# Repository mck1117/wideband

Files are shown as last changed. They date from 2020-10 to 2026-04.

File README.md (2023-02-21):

 

# rusEFI Wideband Controller

[User Documentation](https://rusefi.com/s/wb)

[Forum Thread](https://rusefi.com/forum/viewtopic.php?f=4&t=1856)

## Building Firmware

The `firmware/boards` directory contains configuration for each board this firmware supports.

For the standalone board and the module built in to rusEFI Hellen boards, `f0_module` is the correct target.  Use the `build_wideband.sh` script to build and package the wideband firmware: both a bin including the bootloader, and a header file consumed by rusEFI that contains no bootloader, to be uploaded over CAN (via the aforementioned bootloader).

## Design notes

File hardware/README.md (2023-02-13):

## `board_module`

Wideband O2 sensor controller on a postage stamp. Contains all the analog and digital control logic to handle a Bosch LSU 4.2, 4.9, or ADV sensor.

Intended to either be mounted on an ECU as a module, or on `board_carrier` to run standalone.

## `board_carrier`

Stacks under `board_module`, has 5v regulator, CAN tranceiver, etc so that the module can exist standlone.

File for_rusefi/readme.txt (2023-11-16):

The file wideband_image.h is generated for use by rusEFI to be able to beam firmware updates to attached wideband controllers.

Use ``cd firmware/boards/f0_module ; ./build_wideband.sh`` to build a fresh version.

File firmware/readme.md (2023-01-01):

# Implementation Details

Main logic is executed at a few KHz frequency (Bosch spec is 1-4KHz), driven by carefully selected ADC settings.

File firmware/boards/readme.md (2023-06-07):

Both single-channel and dual-channel F103 boards live at https://github.com/rusefi/rusefi-hardware

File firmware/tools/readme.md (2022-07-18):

* wideband.bin
 initial firmware with botb OpenBLT and current wideband firmware.

* wideband_update.srec
 rusEFI wideband firmware for OpenBLT-via-CAN or OpenBLT-via-uart update methods.

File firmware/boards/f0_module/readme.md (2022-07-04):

Firmware for reference https://github.com/mck1117/wideband/tree/master/board_module F0 hardware.

Also the firmware for https://github.com/andreika-git/hellen-one/tree/master/modules/wbo.

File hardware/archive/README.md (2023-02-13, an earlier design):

This folder is old hardware preserved for posterity.

## `board_dev`

Developmend board used to prove out principle before the F0 module was developed.

## `board_fw_tool`

Used to connect USB to the F0 module before the debug header was replaced with Tag Connect TC2030.

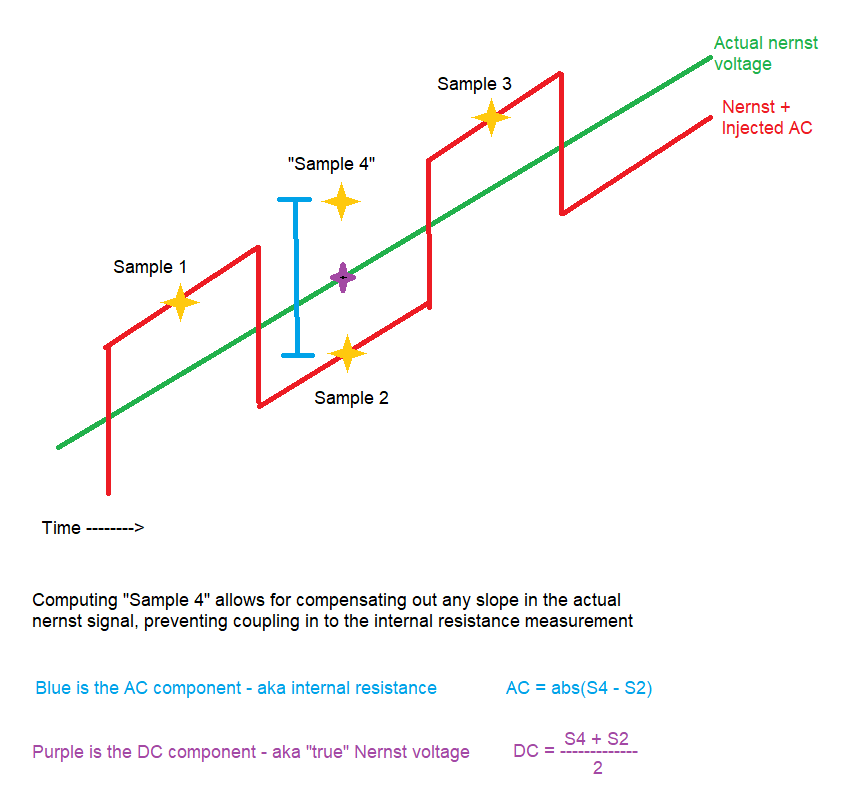
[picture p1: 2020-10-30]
firmware/sampling.png

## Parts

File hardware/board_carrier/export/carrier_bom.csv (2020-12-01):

Comment | Designator | Footprint | LCSC
1u | C1,C2,C3 | Capacitor_SMD:C_0603_1608Metric | C15849
47p | C4,C5 | Capacitor_SMD:C_0402_1005Metric | C1567
D_TVS | D1 | Diode_SMD:D_SMC | C133648
D_Schottky | D2 | Diode_SMD:D_SMA | C8678
220 | R1 | Resistor_SMD:R_0603_1608Metric | C22962
470 | R2 | Resistor_SMD:R_0603_1608Metric | C23179
TJA1051T-3 | U1 | Package_SO:SOIC-8_3.9x4.9mm_P1.27mm | C38695
LM78M05_TO252 | U2 | Package_TO_SOT_SMD:TO-252-2 | C58069

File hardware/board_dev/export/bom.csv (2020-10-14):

Comment | Designator | Footprint | LCSC
1u | C1,C4,C7,C14,C16 | Capacitor_SMD:C_0402_1005Metric | C52923
4.7u | C10 | Capacitor_SMD:C_0603_1608Metric | C19666
100n | C2 | Capacitor_SMD:C_0603_1608Metric | C14663
33n | C3 | Capacitor_SMD:C_0402_1005Metric | C1585
1n | C6 | Capacitor_SMD:C_0402_1005Metric | C1523
100n | C8,C5,C9,C11,C13,C12 | Capacitor_SMD:C_0402_1005Metric | C1525
RED | D1 | LED_SMD:LED_0603_1608Metric | C2286
GREEN | D2 | LED_SMD:LED_0603_1608Metric | C72043
BTS3028 | Q1 | Package_TO_SOT_SMD:TO-252-2 | C112639
61.9 | R10 | Resistor_SMD:R_0603_1608Metric | C23092
51k | R13 | Resistor_SMD:R_0402_1005Metric | C25794
3.3k | R14,R16,R24 | Resistor_SMD:R_0402_1005Metric | C25890
100k | R15,R17 | Resistor_SMD:R_0402_1005Metric | C25741
10k | R2,R11,R12,R4,R3,R18,R21,R20,R19,R29,R1,R33,R34 | Resistor_SMD:R_0402_1005Metric | C25744
10k | R22 | Resistor_SMD:R_0603_1608Metric | C25804
33 | R23 | Resistor_SMD:R_0402_1005Metric | C25105
1k | R25,R26,R27,R30 | Resistor_SMD:R_0402_1005Metric | C11702
68k | R32,R31 | Resistor_SMD:R_0402_1005Metric | C36871
22k | R6 | Resistor_SMD:R_0402_1005Metric | C25768
27k | R7,R5 | Resistor_SMD:R_0402_1005Metric | C25771
47 | R8 | Resistor_SMD:R_0402_1005Metric | C25118
10 | R9 | Resistor_SMD:R_0402_1005Metric | C25077
MCP6004 | U1,U2 | Package_SO:TSSOP-14_4.4x5mm_P0.65mm | C50282
STM32F042K6Ux | U4 | Package_DFN_QFN:QFN-32-1EP_5x5mm_P0.5mm_EP3.45x3.45mm | C110616
XC6206P332MR | U9 | Package_TO_SOT_SMD:SOT-23 | C5446

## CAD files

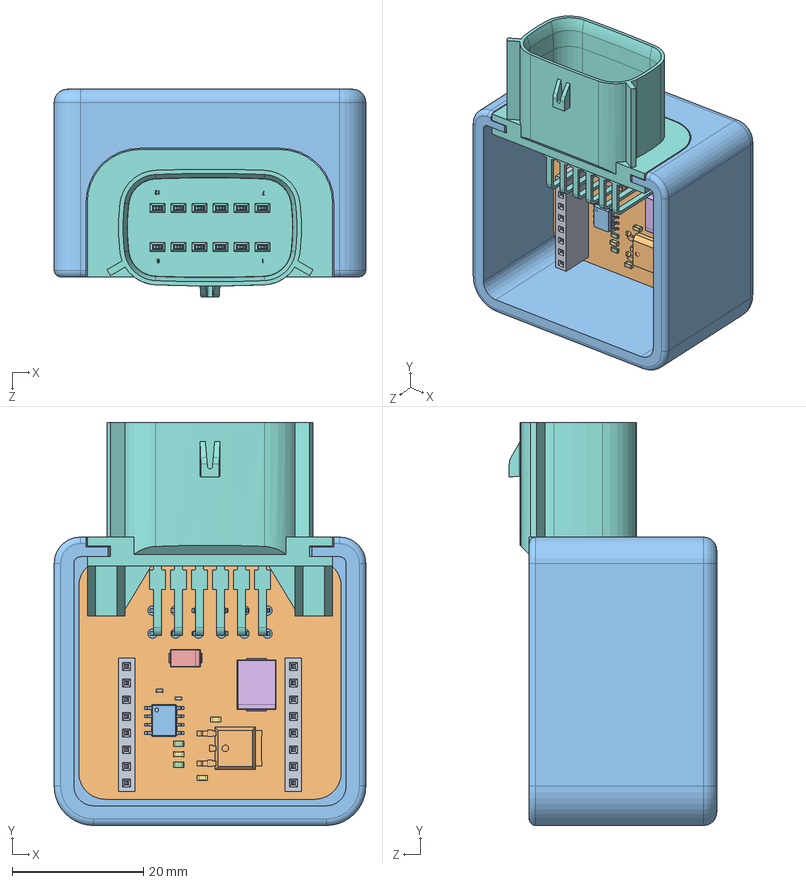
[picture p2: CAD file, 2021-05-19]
case/board_carrier.step.SLDASM
47.5 x 61.4 x 31.6 mm
SOLID.step x 2
SOLID-0.step
SOLID-1.step
SOLID-2.step x 2
SOLID-3.step
SOLID-4.step
SOLID-5.step x 3
COMPOUND.step
SOLID-6.step x 2
COMPOUND-7.step
Part13^board_carrier.step

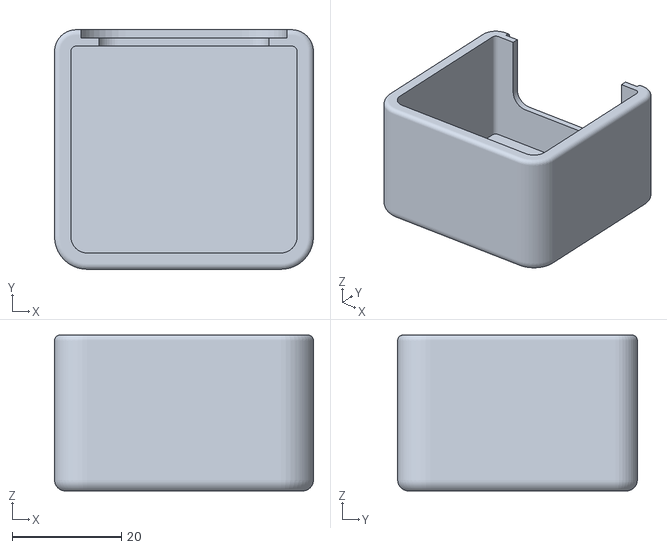
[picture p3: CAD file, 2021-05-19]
case/case.STL
47.5 x 44.0 x 28.6

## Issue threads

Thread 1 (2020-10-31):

programming usability and cheaper option

rusefillc, 2020-10-31:
At the moment that's a $8 with quantity 10 mostly assembled PCB which requires a $3.5 FTSH-107-01-F-DV-K

Please add TC2030 footprint like on microRusEFI since it's "free" and/or maybe some other programming option - 0.1" header? "program" button or jumper?

mck1117, 2020-10-31:
current board is a proof of concept/development board - no reason to not use a $4 connector there.  The "real thing" won't need it, instead firmware upload over UART DFU or something.  I don't really need debugging facilities on the production one, and if I decide I do, a few test pads for SWD are good enough.

Closed 2020-10-31.

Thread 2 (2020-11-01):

opamp alternatives

mck1117, 2020-11-01:
Possible alternatives to the MCP6004:

|PN|Vos typ|Rail-to-rail?|JLC cost @qty 10|
|--|--|--|--|
|MCP6004|4.5mV|25mV|$0.29|
|AD8609|40uV|~20mv|$2.20|
|OPA4377|250uV|10-20mV|$1.38|
|RS8559XQ|20uV|10mV|$0.54|
|MCP6L04|1mV|35mV|$0.25|

mck1117, 2020-12-11:
switched to ad8628 on the module

Closed 2020-12-11.

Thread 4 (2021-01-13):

Embeddable module

rusefillc, 2021-01-13:
I am interested in a single self-contained PCB block for embedding into other boards

A rectangle KiCad without holes for connectors but with all connectivity routed to edges and a footprint symbol

rusefillc, 2021-06-13:
we now have https://github.com/andreika-git/hellen-one/wiki/module-wbo

Closed 2021-06-13.

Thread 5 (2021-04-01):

chip shortage in 32 pin package

rusefillc, 2021-04-01:
as is we use STM32F042K6Tx

STM32F042K6T6 or STM32F042K6T7

https://jlcpcb.com/parts/componentSearch?searchTxt=stm32%20p-32

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

would STM32F103C8T6 or STM32F030C8T6 or else in 48 pad package be an option?

rusefillc, 2021-04-13:
chip shortage is harder on chips with CAN. can we add analog output into WBO module please? i like analog more than uart while we are in survival mode and we will go back to CAN once we can?

Closed 2022-08-17.

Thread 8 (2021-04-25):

clamp esr over CAN to prevent overflow

mck1117, 2021-04-25:

mck1117, 2021-04-28:
Done in master.

Closed 2021-04-28.

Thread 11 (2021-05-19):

hardware support for hard-coded index

mck1117, 2021-05-19:
Somehow we need to hard-code index on PnP hellen boards with multiple controllers.  It's impossible to unplug one controller to set index, since they're all hard wired on the same pcb.

mck1117, 2021-05-19:
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

mck1117, 2021-05-19:
For legacy boards without jumpers, pins were selected such that ID 0 and 1 are possible by bridging to adjacent power pins:
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

mck1117, 2021-05-19:
now supported via 48dbdb842eae69c1f04c9a79e712a42da6d8ad18

Closed 2021-05-28.

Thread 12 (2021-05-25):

Analog output

rusefillc, 2021-05-25:
Humans are looking for wideband 0-5v analog output. Maybe a simple 0-3v output would do?

mck1117, 2021-05-26:
Which humans? Why? We want to promote rusEFI, so why not encourage CAN?

rusefillc, 2021-05-26:
Questionable cheap humans for sure, but being known for a good & cheap WBO could be the long shot way to get people familiar and comfortable with RE.

shinobisystems, 2021-09-28:
Support the addition of an analogue output line (pref 0-5v) on the connector for correlation to gauges for non-EFI / Other ECU applications.. Lets make it available to Everyone out there to prove the Products Superiority (as well as Flexibility)...

Closed 2022-08-17.

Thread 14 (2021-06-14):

We need a 52mm screen option

rusefillc, 2021-06-14:
Without an easy to install gauge we are just taking too much risk in my opinion

Closed 2022-08-17.

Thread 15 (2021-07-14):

Make CAN protocol option to emulate MoTeC LTC/D.

kjngineering, 2021-07-14:
The MoTeC LTC (Lambda to CAN) devices are essentially the exact same functionality of this device.
The price of these devices is ~$380USD for the single channel version and $500USD for the dual.

Consider the commercial option of matching the can protocol to the MoTeC device as described here (Appendix E):
https://www.motec.com.au/filedownload.php/LTC%20User%20Manual.pdf?docid=3001

This would not be the first device to go down this route with the Bosch Motorsport Lambdatronic LT2 sport being available with a "MoTeC Compatible" CAN bus protocol:
https://cdn.shopify.com/s/files/1/0057/7712/9587/files/LT2_Sport_Lambda_Measurement_Device_-_Datasheet.pdf

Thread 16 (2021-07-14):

Add hardware for onboard voltage sensing.

kjngineering, 2021-07-14:
Currently the controller uses the voltage sensed at the ECU and transmitted via CAN to adjust the heater PID.
Chassis wiring and ground points could mean reasonable differences between the battery voltage at the module and the ECU.

Suggest incorporating an ADC channel and appropriate divider on the module to measure "local" battery voltage for heater compensation.

rusefillc, 2023-02-03:
Another argument for same would be having 042 design self-contained.

rusefillc, 2023-02-03:
https://rusefi.com/forum/viewtopic.php?p=47055#p47055

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

rusefillc, 2023-02-03:
Another option https://github.com/mck1117/wideband/issues/194

mck1117, 2023-02-03:
hardware done 6831f5a1ae87e985e1e40e1fd2b6fe2107d40a72

Closed 2023-02-04.

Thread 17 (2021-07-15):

Add switchable RC circuits to support LSU-4.9 and LSU-ADV?

kjngineering, 2021-07-15:
Much like the ST driver it makes sense to have switchable RC circuits to support different sensors.
Eventually the LSU-ADV will become the standard part.

rusefillc, 2022-04-04:
https://www.bosch-motorsport.com/content/downloads/Raceparts/Resources/pdf/Data%20sheet_69086859_Lambda_Sensor_LSU_ADV/ADV_pre_Turbo.pdf

@kjngineering any part numbers for me to purchase a test LSU-ADV for @dron0gus?

kjngineering, 2022-04-04:
Updated datasheet with Bosch Global PN: https://www.efisolutions.com.au/assets/brochures/135-017.pdf

Post-Turbo: 0 258 027 010
Pre-Turbo: 0 258 027 211

Some Links:
https://www.14point7.com/products/lsu-adv-wideband-o2-sensor
https://www.efisolutions.com.au/bosch-sensor-lsu-adv-wideband-sensor

rusefillc, 2022-04-04:
@kjngineering while those are amazing links i would expect something more OEMish to be cheaper?

either OEM has used ADV somewhere (and we should learn where) or if ADV is just for the fanciest guys there maybe we are not there yet

kjngineering, 2022-04-04:
I did see some OEM cross reference for these but they were out of stock and around the 80EUR level. What is the preferred country of purchase?

rusefillc, 2022-04-04:
USA new/used ebay.com
RU used by model/year

my focus is mostly to make sure that we have a "proper" source

kjngineering, 2022-04-04:
So its apparently the same as Audi/VW/Porsche: 06L906262 (unconfimed)

https://www.ebay.com/itm/334323999253

rusefillc, 2022-04-04:
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

kjngineering, 2022-04-04:
> 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

This is bosch OE 0 258 027 174, according to the product subcategory on buycarparts.co.uk this is a LSUADV sensor.
However, according to the information available on the Audi catalog this is a pre-turbo variant.

The 'best' way to identify a LSU-ADV at the moment is the connector type, they have 5 pins and no internal trim resistor. (this sensor is in line with this information).

mck1117, 2022-04-04:
> this is a pre-turbo variant.

I think the pre-turbo operates the same as the "normal" LSU ADV, but has different thermal behavior

rusefillc, 2022-04-07:
Some info at https://rusefi.com/forum/viewtopic.php?p=44904#p44904

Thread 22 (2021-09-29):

mosfet PN alternatives

rusefillc, 2021-09-29:
See https://github.com/andreika-git/hellen-one/issues/96

Closed 2022-08-17.

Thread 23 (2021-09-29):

through-hole option for MOSFET

rusefillc, 2021-09-29:
See https://github.com/andreika-git/hellen-one/issues/97 as ultimate chip shortage solution

mck1117, 2021-09-29:
Nope, not worth the vibration risk here.  There are plenty of protected DPAK low side drivers.

Closed 2021-09-29.

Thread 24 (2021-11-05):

Access to I2C bootloader

rusefillc, 2021-11-05:
it would be great to reduce manual labor while boards assembly, is there a way to big rusEFI to program WB controllers from scratch?

stm32f042 does not have CAN bootloader. What about I2C? what level of effort on HW and SW side to get all that to work?

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

Closed 2022-08-17.

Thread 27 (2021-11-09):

Carrier, Parts shortage, BOM D1

rusefillc, 2021-11-09:
D1 | D_TVS | SMCJ30CA-TR not available right now any alternatives?

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

rusefillc, 2021-11-10:
@blundar says
SMCJ28CA C10245
C111086 SMCJ30CA

Closed 2022-08-17.

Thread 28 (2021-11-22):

F103 port of firmware

rusefillc, 2021-11-22:
We have https://github.com/mck1117/wideband/tree/master/firmware compiled with https://github.com/mck1117/wideband/tree/master/firmware/boards/f0_module running on https://github.com/mck1117/wideband/tree/master/board_module - that's working F042 reference

We also have untested F103 version of the hardware https://github.com/rusefi/rusefi-hardware/tree/main/wideband-F103 which still needs firmware

Looks like https://github.com/mck1117/wideband/tree/master/firmware/boards/f1_dave is the skeleton which needs F103-specific details

rusefillc, 2022-01-11:
open issues:
1) CANConfig
1) software PWM callback for output toggle

Closed 2022-08-17.

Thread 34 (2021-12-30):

Wideband failed to startup after cranking

BeerMoneyMotorsports, 2021-12-30:
Log Below- wbo never showed a reading after engine started.  after a few minutes, i did a firmware write on the wbo while engine running.  45 seconds later, wbo was reading like it should.

https://rusefi.com/online/view.php?log=524

BeerMoneyMotorsports  6:00 PM
@Matthew Kennedy so i have noticed an issue with wbo when long cranking.  i will try to get a log of it and create an issue.
It seem that if you take too long to start or it fails to start, the sensor will not read.  I noticed this while testing on this NB1.

Matthew Kennedy  6:00 PM
hm

BeerMoneyMotorsports  6:00 PM
i have let it run after the car started for a couple minutes
6:00
sensor never shows up

Matthew Kennedy  6:00 PM
loggy log in wbo debug mode

BeerMoneyMotorsports  6:01 PM
i can flash the wbo firmware real quick and then it will heatup and work
6:01
while engine is still running

Matthew Kennedy  6:01 PM
yea
6:01
whatever thermal conditions you're making are probably just barely outside what it can handle

BeerMoneyMotorsports  6:01 PM
ill do a good log tomorrow and toss it in an issue with a reasonable description

Matthew Kennedy  6:01 PM
which means we just need to widen the envelope of "legal" and/or adjust heater tuning a bit (edited)

BeerMoneyMotorsports  6:02 PM
it seems like its related to the rpm requirement for heating.  does it trip out if jumping between low and high rpm?  or when trig errors occur?

BeerMoneyMotorsports  12:13 PM
@Matthew Kennedy https://rusefi.com/online/view.php?log=524

rusefi.comrusefi.com
rusEFI online
rusEFI tune file sharing site
12:14
wbo never started to read after startup.  after a few minutes, i did a firmware write on the wbo while engine running.  45 seconds later, wbo was reading like it should

BeerMoneyMotorsports  1:36 PM
Which repo do i ticket?

Matthew Kennedy  1:41 PM
Do it in mine
1:41
Probably a bug in the wbo itself

mck1117, 2022-01-10:
likely fixed by 437efb1cc6f5db2aebb5fa5fa3f2d8bebf3716c6

BeerMoneyMotorsports, 2022-01-14:
firmware update but wbo still inop

https://rusefi.com/online/view.php?log=566

BeerMoneyMotorsports, 2022-01-17:
latest firmware (1/17/2022) with no failure.

https://rusefi.com/online/view.php?log=575

Closed 2022-10-03.

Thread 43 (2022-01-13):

F103 no longer blinks

rusefillc, 2022-01-13:
F103 FW was blinking green LED before https://github.com/mck1117/wideband/commit/23a05968d3eaa2c6a9e326138c931f02467fbbad
F103 FW no longer blinks green LED after https://github.com/mck1117/wideband/commit/23a05968d3eaa2c6a9e326138c931f02467fbbad

mck1117, 2022-01-13:
try again with 660dad473ce2e0721438f7be5749fd3e449680c7

rusefillc, 2022-01-13:
it's blinking again!

mck1117, 2022-01-13:
OK, I guess something didn't like 64MHz.  Let's stay at 48 for now then, and maybe speed it up later.

Closed 2022-01-13.

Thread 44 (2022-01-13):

F103 CAN baud rate

rusefillc, 2022-01-13:
Steps to reproduce:
no real WBO hardware needed, blue pull and logic analyzer should be enough (?)

```
cd firmware
make -j12 BOARD=f1_dave
```

before https://github.com/mck1117/wideband/commit/86034506b07e8c83ea32b3456d0b44037c6cc9da we had

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

rusefillc, 2022-01-13:
after https://github.com/mck1117/wideband/commit/86034506b07e8c83ea32b3456d0b44037c6cc9da we have
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

rusefillc, 2022-01-13:
@blundar great news HW works with 250K version of FW

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

mck1117, 2022-01-13:
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

rusefillc, 2022-01-13:
I cannot explain it i just report my test results sorry

rusefillc, 2022-01-23:
Just to confirm - is it OK to test with a blue pill with logic analyzer?

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

thirstyone, 2022-01-24:
don't you need some other devices on the bus?

rusefillc, 2022-01-24:
@thirstyone please consider using more words. We are trying to discuss pretty complex issues here and in my opinion short form is not effective. If you are looking to help please consider typing a bit more works to spell things out a bit more explicitly.

@thirstyone stm32 uses TTL levels on RX and TX pins right? Are you saying that without a real transceiver and without loopback I would never see CAN peripheral TTLing anything readable?

mck1117, 2022-01-24:
> without loopback I would never see CAN peripheral TTLing anything readable?

tie TX and RX together, with a 1k pullup to 3.3v, you don't need a CAN tranciever, but you may need a "bus" enough to fake it.

rusefillc, 2022-01-24:
@thirstyone thank you - with real bus I got 8MHz F103 to work! (alligator clips are wired to CANHacker with 120R)

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

rusefillc, 2022-01-24:
and F103 WBO firmware CAN works as well as is on this blue pill setup, I have no idea what was wrong with my previous experiments on real WBO board

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

Closed 2022-01-24.

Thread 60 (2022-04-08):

Bluetooth

rusefillc, 2022-04-08:
We have UART, we have no screen... Sounds like bluetooth to me?

rusefillc, 2022-04-08:
For hardware see https://github.com/rusefi/rusefi-hardware/issues/58

Closed 2022-08-17.

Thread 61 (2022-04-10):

voltage reference BOM cost

rusefillc, 2022-04-10:
At the moment REF3033  ±0.2% 75ppm/°C 3.3V SOT-23(SOT-23-3) Voltage References is used which is a $1.6 part

Is there a cheaper solution? what level of precision is needed? could it be accomplished with an adjustable reference like AZ432ANTR-E1?

https://datasheet.lcsc.com/lcsc/1810251610_Diodes-Incorporated-AZ432ANTR-E1_C84139.pdf

Closed 2022-08-17.

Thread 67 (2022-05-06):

virtual zero range should be 5v not 3.4v

rusefillc, 2022-05-06:
for better AFR range we shall have wider virtual ground range

mck1117, 2022-05-11:
No need. The circuit was designed to use the full range of the sensor, which we do.

If someone can quantify an actual problem, I am happy to consider it.

rusefillc, 2022-05-11:
is it about higher current in order to get quicker response time?

mck1117, 2022-05-11:
> logging used current

We measure that directly with the pump measurement resistor and amp - then convert to lambda.

We do also directly output the raw pump dac value: https://github.com/mck1117/wideband/blob/2167016c169925023510ef98a7c5abf38c2408f5/firmware/can.cpp#L158

Closed 2022-05-11.

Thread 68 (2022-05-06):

DAC and PID nerst control is not the best control strategy

rusefillc, 2022-05-06:
usecase: in-range measurment adter out-of-range condition

DAC and PID are not best for return to into range phase of control

suggested soltion: analog control, differential op-amp in diff schematic

rusefillc, 2022-05-07:
@mck1117 says

our digital loop runs at ~2khz
if it ran at 10hz maybe

but we're much faster than the bandwidth of the sensor

shannon/nyquist say digital and analog are "the same" if you're sufficiently faster than the bandwidth of any signal you care about

mck1117, 2022-05-11:
I have yet to see a problem with it. I've seen full scale swings (in closed loop!) in <0.1 second.

Closed 2022-05-11.

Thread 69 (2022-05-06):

780C is very imporant

rusefillc, 2022-05-06:
nerst cell resistance control by variable voltage - sin wave etc

NIck RMS says that keeping (heater?) at precisely 780C is really important. Sin wave was a suggested implementation detail.

mck1117, 2022-05-11:
wat?

rusefillc, 2022-05-11:
@dron0gus do you want to get in touch with Nick RMS and do the translation? :)

dron0gus, 2022-05-12:
@rusefillc yes, I can try.

Closed 2022-08-17.

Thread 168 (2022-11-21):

AUX output

pink-fr3ud, 2022-11-21:
Hi,
Thank you for sharing this.
I was looking at your schematics to design a board with in stock components from JLCPCB assembled
I can't find where the analog output is, as stated in the forum https://rusefi.com/forum/viewtopic.php?f=4&t=1856
In fact, the STM32F042K6T6 doesn't provide a DAC at all...? I see in auxout.cpp you are doing some PWM things, is it how you produce the analog signal?
The STM32G030K6T6 go for as little as $1.1150, is pin to pin compatible, faster, has more memory, DAC ... newer. Maybe a good candidate?

rusefillc, 2022-11-21:
> HI can't find where the analog output is, as stated in the forum https://rusefi.com/forum/viewtopic.php?f=4&t=1856

There are 131 posts in that https://rusefi.com/forum/viewtopic.php?f=4&t=1856 thread please be more specific?

Original hardware design does not have AUX output on purpose, it's only the F103 alternative designs which are trying to add aux output. But those F103 efforts are in a bit of an unclear state poke @dron0gus

See also #12

pink-fr3ud, 2022-11-21:
Sorry I was refering to #1 post :
"Support both in-ECU use, as well as standalone. That means SPI or serial comms with an ECU, and CAN or analog for external use."
My bad I didn't see that the F103 was derivated from your design, and indeed he confirmed the DAC working too
I will read a bit more about it and see if I can propose something similar with another mcu

For sure 1.129 Lambda seems poor enough for most tuning needs
Thank you

mck1117, 2022-11-21:
Internal and external original design options are both CAN bus

Closed 2022-11-21.

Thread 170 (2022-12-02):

hard fault on boot with GCC 11

mck1117, 2022-12-02:
Looks like we hard fault the first time we touch a floating point number when compiled with GCC 11. We're using soft floats (ie, no hardware fpu), what is going on!?

rusefillc, 2022-12-02:
@dron0gus

mck1117, 2022-12-02:
it looks like this might be a gcc11 issue…….stay tuned

dron0gus, 2022-12-02:
I bet on stack overflow. My feeling is that GCC11 produce code that uses more stack.

mck1117, 2022-12-02:
Problem happens on F1, but not F0.

F0 = cortex-m0 aka ARMv6-M
F1 = cortex-m3 aka aARMv7-M

mck1117, 2022-12-02:
|Compiler|F0?|F1?|
|---|---|---|
|GCC 9.3.1|❎|❎|
|GCC 11.3.1|❎|❌|

dron0gus, 2022-12-02:
@mck1117 your master. f1_dual with GD32. GCC11.3.rel1. No HardFault.

```
(gdb) info thread
  Id   Target Id                                                  Frame
  2    Thread 536873560 (Name: main, State: SLEEPING)             chSchGoSleepS (newstate=8 '\b') at ChibiOS/os/rt/src/chschd.c:558
  3    Thread 536873776 (Name: idle, State: CURRENT)              chSchDoPreemption () at ChibiOS/os/rt/src/chschd.c:765
  4    Thread 536876976 (Name: noname, State: SUSPENDED)          chSchGoSleepS (newstate=3 '\003') at ChibiOS/os/rt/src/chschd.c:558
  5    Thread 536877552 (Name: noname, State: SLEEPING)           chSchGoSleepS (newstate=8 '\b') at ChibiOS/os/rt/src/chschd.c:558
  6    Thread 536878056 (Name: noname, State: SLEEPING)           chSchGoSleepS (newstate=8 '\b') at ChibiOS/os/rt/src/chschd.c:558
  7    Thread 536880360 (Name: noname, State: SLEEPING)           chSchGoSleepS (newstate=8 '\b') at ChibiOS/os/rt/src/chschd.c:558
  8    Thread 536875744 (Name: noname, State: QUEUED)             chSchGoSleepS (newstate=4 '\004') at ChibiOS/os/rt/src/chschd.c:558
  9    Thread 536876456 (Name: noname, State: QUEUED)             chSchGoSleepS (newstate=4 '\004') at ChibiOS/os/rt/src/chschd.c:558
  10   Thread 536879864 (Name: Primary TS Channel, State: QUEUED) chSchGoSleepS (newstate=4 '\004') at ChibiOS/os/rt/src/chschd.c:558
  11   Thread 536878824 (Name: egt, State: SLEEPING)              chSchGoSleepS (newstate=8 '\b') at ChibiOS/os/rt/src/chschd.c:558

```

mck1117, 2022-12-02:
can you attach your `wideband.elf`/`wideband.list`/`wideband.map` that are working?

dron0gus, 2022-12-02:
[wideband.zip](https://github.com/mck1117/wideband/files/10144405/wideband.zip)

mck1117, 2022-12-03:
no crash running your elf on my board

mck1117, 2022-12-03:
double interesting: running the build from github actions does NOT crash, works fine

mck1117, 2022-12-03:
I had a bad compiler install, it turns out if you end up with the wrong `bits/c++config.h`, strange things happen!

Closed 2022-12-03.

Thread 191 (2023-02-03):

kicad5 or kicad 6?

rusefillc, 2023-02-03:
Is this repo using kicad 5 or kicad 6 or is the intention to support both?

mck1117, 2023-02-03:
as of yesterday it's a split because the module is now 6

rusefillc, 2023-02-03:
should https://github.com/mck1117/wideband/blob/master/hardware/board_module/wideband_controller.pro be removed?

mck1117, 2023-02-03:
8dee668662ecc28bb1afb52380e18ca647ca92fd

Closed 2023-02-03.

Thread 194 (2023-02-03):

042 design as standalone not rusEFI WBO

rusefillc, 2023-02-03:
Could current 042 offering be used not on rusEFI as is?

What are all the gaps between current design and not-rusEFI usage?

* battery input only via CAN?  https://github.com/mck1117/wideband/issues/16
* limited SEL options? https://github.com/mck1117/wideband/issues/193

Anything else?

rusefillc, 2023-02-28:
Poke :) Looks like we have relevant HW progress but no SW progress? Was HW progress a fluke? Is it complete?

rusefillc, 2023-11-15:
How about fallback to some hard-coded voltage assumption if no CAN RX happens for x number of seconds?

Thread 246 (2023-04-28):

Bosch sensors

ChubbyBunny1, 2023-04-28:
Not sure if here is the correct place to ask a question.
I have bought an bosch LSU4.9 that is specific fitment for some vehicles. The part number is 0258017617. Is there any chance that this sensor is specific to some vehicle ECUs? Also what are the differences on theese all bosch LSU4.9 sensors apart from their cable length?

ChubbyBunny1, 2023-04-28:
Thanks for the info, i bought it from theese generic online parts store where you place your VIN and it gives you parts for your car with differnt pricing and company selections. It says bosch and the price was 60euros. Once arrived, i compared it to known original bosch LSU4.9 and the writings and the markings seemed legit.

mck1117, 2023-04-29:
I'll close for now then. If you end up having a problem with a particular (but legitimate Bosch) sensor, come back and we'll have a look.

Closed 2023-04-29.

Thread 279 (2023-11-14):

is anything broken on this log?

rusefillc, 2023-11-14:
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

[wbo-log.zip](https://github.com/mck1117/wideband/files/13345168/wbo-log.zip)

mck1117, 2023-11-15:
the state of the heater request should be in that log too

mck1117, 2023-11-16:
Looks like the ECU isn't requesting the heater to be on, so it isn't trying to heat. Everything looks fine from WBO side.

Closed 2023-11-16.

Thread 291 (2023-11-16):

switch to use libfirmware timer

mck1117, 2023-11-16:
Current issue:

Why is this here, instead of util.mk?
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

rusefillc, 2023-11-16:
I assume that timer.cpp assumes some "abstract" methods are implemented by the consumer.

In order for consumers to have an option not to use timer.cpp and thus not implement dependencies it's currently not in util.mk

I am open to all improvements! At the moment I believe the consumers of libfirmware are ECU, WBO, GDI4 and stim.

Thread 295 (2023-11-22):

65 seconds to detect lack of sensor

rusefillc, 2023-11-22:
"first release" firmware on hellen 042 WBO hardware
4.9 sensor not unplugg

at the moment it takes 65 seconds to detect error condition. wondering if that could be improved?

[2023-11-22_14.47.52 first release no sensor.mlg.zip](https://github.com/mck1117/wideband/files/13443939/2023-11-22_14.47.52.first.release.no.sensor.mlg.zip)

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

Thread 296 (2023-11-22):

how fast do we expect things to start?

rusefillc, 2023-11-22:
hellen 042
first release

not first start today - exhaust and sensor are not completely cold

yet it seems to take ~45 seconds to see WBO reasing
(also all that time fault code is just 0 maybe I shall migrate to fresh binary)

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
[2023-11-22_14.52.35 with sensor.mlg.zip](https://github.com/mck1117/wideband/files/13443961/2023-11-22_14.52.35.with.sensor.mlg.zip)

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

rusefillc, 2023-11-23:
Now with today snapshot https://github.com/rusefi/wideband/releases/tag/20231122-2 60 seconds to report AFR.

is it a coincidence that I had to touch throttle to get reading? Can wideband detect "too lean" and "too rich" and report those as separate states?

[2023-11-22_21.56.09 mck master.mlg.zip](https://github.com/mck1117/wideband/files/13445713/2023-11-22_21.56.09.mck.master.mlg.zip)

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

mck1117, 2023-11-23:
@rusefillc give it another try with current master

mck1117, 2023-11-23:
> is it a coincidence that I had to touch throttle to get reading?

nope, that's just a coincidence.

> Can wideband detect "too lean" and "too rich" and report those as separate states?

It could detect that the pump drive is pinned against the stop (and so the nernst voltage isn't being controlled at ~0.45v), we could at least clear the valid bit when that happens.

rusefillc, 2023-11-23:
latest artifact is silent on the CANbus. just reverted to the not-hanging version and CANbus has returned

will now try latest one more time

rusefillc, 2023-11-23:
progress! we now get AFR in about 20 seconds from engine start

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
[2023-11-22_22.55.22 ver3.mlg.zip](https://github.com/mck1117/wideband/files/13445907/2023-11-22_22.55.22.ver3.mlg.zip)

mck1117, 2023-11-23:
> clear the valid bit when that happens

this is detected and transmitted in ea46db500f6f59fcefe6273ae104fb3fde2bce23

Closed 2023-11-23.

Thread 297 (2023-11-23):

042 master hangs up after a couple of seconds

rusefillc, 2023-11-23:
just programmed https://github.com/mck1117/wideband/commit/f784d5d5b91b0d4528596ff69e7f543b37e84ff9 artifact into hardware which is known to run https://github.com/mck1117/wideband/releases/tag/first-release

I see a second of green and blue LED blinking and then both lights go off. Also no data on the CANbus

mck1117, 2023-11-23:
it's overflowing RAM and for some reason the linker isn't catching it

Closed 2023-11-23.

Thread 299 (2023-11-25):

brand new sensor failed to heat

rusefillc, 2023-11-25:
042 hellen module
june release

[wbo-stars.zip](https://github.com/mck1117/wideband/files/13464705/wbo-stars.zip)

mck1117, 2023-11-26:
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

based on the 0.3v jump in battery voltage when the heater kicks off, I'm going to blame weak wiring/psu here

rusefillc, 2023-11-26:
That's on a real bike with a small battery. WBO located on same PCB as main connector hooked to OEM harness.

rusefillc, 2023-11-27:
here's a new log with heater+ taken from a better spot - VBatt jump is much smaller, still failed to warm up

[WBO2 LOG with battery power to heater +.zip](https://github.com/mck1117/wideband/files/13468564/WBO2.LOG.with.battery.power.to.heater.%2B.zip)

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

mck1117, 2023-11-27:
try it with the new bin that heats more aggressively

rusefillc, 2023-12-05:
things are better with 2111 pre-release

[DataLogs12-5_LF1.zip](https://github.com/mck1117/wideband/files/13573435/DataLogs12-5_LF1.zip)

new issue https://github.com/rusefi/rusefi/issues/5773

Closed 2025-01-28.

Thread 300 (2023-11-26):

Modifying code for the F0 board

ChubbyBunny1, 2023-11-26:
Can anyone give some directions on how to modify and upload the code to the F0 board, what IDE to use, workflow. I have an ST-LINK V2 and CubeIDE installed

Thank you

mck1117, 2023-12-06:
Hi, what changes are you trying to make? If it's something that would be useful for others too, I'd be happy to implement them and get them in to official builds.

ChubbyBunny1, 2023-12-06:
I am trying to make an analog output. I modified the PCB and added an opamp with RC filter at PB1 (TIM3_CH1) in order have outpt 0-5V analog. Since timer 3 is set up at high frequency it should be easy to add an extra PWM out right?

rusefillc, 2023-12-06:
> I am trying to make an analog output.
have you seen F103 boards doing this with a DAC?

ChubbyBunny1, 2023-12-06:
> > I am trying to make an analog output.
>
> have you seen F103 boards doing this with a DAC?

Yes ofcource but i want to make this board work with analog output too.

Closed 2025-01-28.

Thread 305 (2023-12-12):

DBC file broken

dynfer, 2023-12-12:
The DBC file when viewing its source or via a tool displays an bogus frame ID.

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

Tested on:
https://www.csselectronics.com/pages/dbc-editor-can-bus-database

VSCode extension
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

https://github.com/mck1117/wideband/blob/master/wideband-can.dbc

rusefillc, 2023-12-12:
@dynfer I would assume that vector CANdb++ is _the_ official too? Is not that tool free?

DBC is a proprietary standard by vector is not it?

mck1117, 2023-12-12:
I created it and it opens just fine in Kvaser Database Editor:

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

dynfer, 2023-12-12:
@rusefillc to my knowledge its the official however the program is not free to use hence the other tools I've used to view it.
If it is proprietary I cannot tell.

@mck1117 I assume then this adress is correct and not an error?

mck1117, 2023-12-12:
That address is correct, yes.

dynfer, 2023-12-12:
All clear thanks

Closed 2023-12-12.

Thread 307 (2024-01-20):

Weird behaviour of hand soldered F0 board runing latest firmware

dynfer, 2024-01-20:
Hello,

I have two f0 boards which have two different behaviours, both running November firmware from mck1137/wideband.

1. Nerst voltage fluctuates depening on the applied oxygen (sensor over candle or lighter) afr sometimes jumps if nerst crossed over 450mV
2. Nerst voltage stays fixed at around 450mV, pump current changes depending on applied oxygen, AFR stays pretty much fixed at around 15.45

I've attached logs from both boards 2024-01-18_18.02.05.zip

Both boards are hand assembled so there might an issue with soldering??

//EDIT
I've verified all solder joints and now both units behave like in the log below, the spikes are nerst V and pump DC are from me applying propane to the sensor 2024-01-18_21.41.24.zip
[2024-01-18_18.02.05.zip](https://github.com/mck1117/wideband/files/13998219/2024-01-18_18.02.05.zip)
[2024-01-18_21.41.24.zip](https://github.com/mck1117/wideband/files/13998221/2024-01-18_21.41.24.zip)

rusefillc, 2024-01-20:
@dynfer please describe your power supply

@dynfer maybe add a photo of the overall setup?

dynfer, 2024-01-20:
> @dynfer please describe your power supply
>
> @dynfer maybe add a photo of the overall setup?

For power I've used a AC/DC 12V 1A power brick and 12v from PC power supply both shared the behaviour

Only thing that would differ from a standard setup that I have soldered wires directly to the pins of the 12pin connector on the carrier board instead of using the connector itself.

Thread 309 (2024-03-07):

inputs are not protected

rusefillc, 2024-03-07:
I've hooked up stm32f042 wideband module to a mis-wired cable.

heater wire into into Vm has caused flowing red stm32f042

mck1117, 2024-03-07:
well that's exciting

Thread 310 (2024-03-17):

What's the status of rev B HW? Was it tested? Is FW available for rev B hardware?

rusefillc, 2024-03-17:
%subj% see https://rusefi.com/forum/viewtopic.php?p=49347#p49347

mck1117, 2024-03-17:
Rev B works great. Current Beer Money Motorsports ECUs use the rev B module.

Same firmware works on rev A or B.

Closed 2024-03-17.

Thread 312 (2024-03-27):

Nernst voltage is not regulated to 450 mV

ME12451, 2024-03-27:
I have this weird behaviour where the Nernst voltage is not regulated to 450 mV.

See also: https://rusefi.com/forum/viewtopic.php?f=17&t=2740

Is there a way to debug the device, so I could specify the problem further?

mck1117, 2025-01-24:
this is not the place for user support

Closed 2025-01-24.

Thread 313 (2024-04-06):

Old parameters in uart.cpp and linking error

Theo-Point, 2024-04-06:
Hello,
I'm trying to use the serial debug functionnality on a custom standalone F0 board in order to debug a non-trivial heater state error. (over heated on closed loop after 5s, I tried the no heater state branch).

So i defined a DEBUG_SERIAL_PORT according to other boards config but i get few errors :

- First one was the ChibiOS serial driver not being included. But by including the correct file it's all good.

- The second one was that after a certain commit (i looked it up but i can not find it anymore) you changed the `GetSampler(ch)` function and removed the parameter for the channel but it's still there in this optionnal part of uart.cpp
So in the uart thread, `GetSampler(ch).GetNernstDc(ch)` should be `GetSampler().GetNernstDc(ch)` etc...
The problem is the same for `(GetSampler(ch).GetNernstAc(ch)`, `GetSampler(ch).GetSensorInternalResistance(ch)`, `GetSampler(ch).GetSensorTemperature(ch)` and `GetSampler(ch).GetPumpNominalCurrent(ch)`.

After that change it compiles but when linking an error is thrown telling me that according to the linker script, the stm32 doesn't have enough RAM. I can't give you the exact error because my stm32 fried or my st-link did. But it was too much by around 600 bytes. (I tried to remove max3185x.cpp from the project but i just reliased that it was not compiled due to no EGT channels)

Does anyone had this error when trying to use the serial debug functionality on f0 boards ?
Should I open a pull request to modify uart.cpp ?

Thanks for all you work ! 👍

dron0gus, 2024-04-06:
I think no one try serial debug output on f0.
Easiest way to get debug is to connect f0 module to some RusEFI ecu and write log. Wbo emits debug can message, rusefi includes ot into log.
F0 us limited in resources, you can try disabling bootloader to free some flash. But if you are out of RAM this will not help.

dron0gus, 2024-04-06:
Also double check that your Ip current pump is working and correctly connected. Without feeding pump temperature measurement can go wrong.

Theo-Point, 2024-04-06:
Thanks for your response !

I ordered new components for now so I wont be able to try for now, but i will give it a go.

dron0gus, 2024-04-06:
Also you can try this test branch https://github.com/dron0gus/wideband/tree/underheat-issue . Issue is still in debug, but looks similar to yours.

mck1117, 2024-04-06:
> Also you can try this test branch https://github.com/dron0gus/wideband/tree/underheat-issue . Issue is still in debug, but looks similar to yours.

PR?

rusefillc, 2024-04-06:
> PR?

could be blocked by https://github.com/mck1117/wideband/pull/294

dron0gus, 2024-04-07:
@mck1117  https://github.com/mck1117/wideband/pull/314 . But needs more testing.

Closed 2025-01-24.

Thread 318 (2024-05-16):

No CANBUS reading from Wideband to Rusefi ECU

NickZ1969, 2024-05-16:
No CANBUS reading from Wideband to Rusefi ECU.
Using original release wideband firmware canbus wideband values are received fine but sensor eventually times out on goes into error.
Using second release no sensor timeout but data is displayed as 0.0 and does not change on rusefi.
using latest firmware from this github data is either 29 or 0.0 and nothing in between on rusefi.

I was using rusEFI master.2024.04.18.f407-discovery.137850894 and now updated to latest Rusefi firmware.

replacing with AEM canbus wideband readings are as expected.

mck1117, 2024-05-16:
What controller? Do you have a log from the ECU of warmup/error? Does the wideband show any error blink code? Does this sensor work with other controllers? Does this controller work with other sensors?

NickZ1969, 2024-05-16:
the wideband controller is this controller on the adapter board.
Im sorry I don't have a log of the wideband, how do I log the wideband controller?
with the latest firmware the controller warms the sensor, green LED goes into slow bling, the heater led shows signs of it regulating the heating and all seems to be working as it should but no data over the canbus. No blue led blink errors. the controller doesn't go into error.
yes the sensor/s works perfect when I switch to my AEM controller and ive driven 100s of km on the AEM without errors in the same car.
I have not had the controller work on any other sensors with the later firmware, The first release works fine for about 5 minutes before going into error on all sensors ive tried. A ignition power off and system will work again for a couple of minutes.
________________________________
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

mck1117, 2024-05-16:
> Im sorry I don't have a log of the wideband, how do I log the wideband controller?

just grab an ECU log, the ECU logs some parameters from the wideband.

NickZ1969, 2024-05-16:
ok i will make a log later in the day and send it.

regards
Nick
________________________________
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

NickZ1969, 2024-05-18:
[2024-05-18_14.45.26.mlg.txt](https://github.com/mck1117/wideband/files/15360434/2024-05-18_14.45.26.mlg.txt)
here is a log from today

VFRenjoyer, 2024-05-19:
I may be having a similar problem on my board with two wideband controllers, the relevant logs are at
https://rusefi.com/online/view.php?log=1396
https://rusefi.com/online/view.php?log=1397

ElDominio, 2024-05-21:
I also have tune and logs: https://rusefi.com/online/view.php?log=1395

NickZ1969, 2024-06-10:
Any updates on this yet?

NickZ1969, 2024-06-10:
Issue was me. pins 1 and 2 where swapped (sensor pins).

mck1117, 2024-06-16:
So this is fixed, and was just a wiring issue?

NickZ1969, 2024-06-16:
My issue yes, was wiring.

ElDominio, 2024-06-21:
Mine wasn't. Changed to an OG AEM Wideband and still doing the same thing

mck1117, 2024-06-26:
> Mine wasn't. Changed to an OG AEM Wideband and still doing the same thing

So also not an issue with this controller.

ElDominio, 2024-06-26:
*included 4.9 with an xseries uego

mck1117, 2024-06-26:
> *included 4.9 sensor with an xseries uego

please use more words or I can't help you

ElDominio, 2024-06-26:
I changed the sensor i was using to the included one with an AEM X-Series UEGO, and it still does the same thing.

I removed my controller and used the X Series controller, and it reads fine.

I will upload my schematics tonight

ElDominio, 2024-07-31:
I changed to yet another and it was fine??!? I have two on my 3000GT and it works; maybe it is the car it's on? some electrical noise or something?

Closed 2024-06-17.

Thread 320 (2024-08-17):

auto-detect bad sensor

rusefillc, 2024-08-17:
I have a dual-WBO ECU and three sensors. I suspect that sensor number two is not good, shall we auto-detect bad sensors like that?

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

[two sensors numbers 1 and 2 flipped.zip](https://github.com/user-attachments/files/16645213/two.sensors.numbers.1.and.2.flipped.zip)

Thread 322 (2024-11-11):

Potential thread stack overflow in function `AuxOutThread`

mirusu400, 2024-11-11:
### Summary

There are potential thread stack overflow in thread function `AuxOutThread`

### Details

https://github.com/mck1117/wideband/blob/4e3e4d75d4073edae20b8eb1fbebbb514c487e75/firmware/auxout.cpp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

In this line, `AuxOutThread` Allows size of `waAuxOutThread`, which is 256 bytes.

However, after manually checking stack, it might have **264** Bytes.

**Steps to reproduce**

For this step, I just use `rusefi` git repo for reproduce.

0. Build rusefi once nomally (environment setup, etc..)

1. Add this flags in `firmware/Makefile`

```diff
...
# Compiler options here.
ifeq ($(USE_OPT),)
  USE_OPT = -O2 -ggdb -fomit-frame-pointer -falign-functions=16 -fsingle-precision-constant
endif

++ USE_OPT += -fstack-usage
...

# Remove LTO for getting stack size dump
++ # Enable this if you want link time optimizations (LTO).
++ # ifeq ($(USE_LTO),)
++ #   USE_LTO = yes
++ # endif
```

2. build again.

Now we can get stack usage file (*.su) for each source file, So we can manually check stack size of each function.

### PoC
**In case of `AuxOutThread`**:
```
AuxOutThread (_Z12AuxOutThreadPv) 104 size
chThdSleep (chThdSleep) 16 size
chThdSleepS (chThdSleepS) 16 size
chSchGoSleepTimeoutS (chSchGoSleepTimeoutS) 40 size
chVTDoSetI (chVTDoSetI) 48 size
port_timer_start_alarm (port_timer_start_alarm) 16 size
stStartAlarm (stStartAlarm) 16 size
st_lld_start_alarm (st_lld_start_alarm) 8 size

=> SUM: 264 bytes
```

So, there are potentially occur stack overflow in `AuxOutThread` Thread function.

I've check all the given controllers and it seems that only `f1_dual` and `f1_rev2` controller have this vulnerability.

mck1117, 2025-03-04:
@mirusu400 what tooling did you use to combine the stack usage and call graph?

> `# Remove LTO for getting stack size dump`

This alters the result - LTO inlines lots of stuff and even removes parameters from functions, so the stack usage is typically strictly less when LTO is enabled.

mck1117, 2025-03-04:
also, looks like `-fstack-usage` still works with LTO on:

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

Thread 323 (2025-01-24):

Fix build for F1 boards

mck1117, 2025-01-24:
Something changed in newer ChibiOS, maybe F1 boards need tweaking to match.

mck1117, 2025-01-24:
@dron0gus @rusefillc interest? I've disable their builds for now on CI 40d264b2f75594527e3e9825ee3856ea6f119d50

dron0gus, 2025-01-27:
ChibiOS needs patching.
STM32_DAC_HAS_MCR should be false for STM32F1xx... And many others...

dron0gus, 2025-01-27:
https://github.com/mck1117/wideband/pull/324
and
https://github.com/dron0gus/ChibiOS/commit/88cef96dd5f86fc5a73e10fc5f3d13ab6030b9b2

mck1117, 2025-01-28:
> ChibiOS needs patching. STM32_DAC_HAS_MCR should be false for STM32F1xx... And many others...

Seems like a good one to upstream to chibios

dron0gus, 2025-01-28:
> Seems like a good one to upstream to chibios

I'll do.

mck1117, 2025-05-28:
> I'll do.

Any news here?

mck1117, 2025-06-20:
looks like as of 1495e705979f87016fbfa484c36777f1f98ff30a, F1 boards are building again

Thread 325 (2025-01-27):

Heater duty oscillating

dron0gus, 2025-01-27:
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
Both channels on F1 dual Rev1. Not observed on my master.

mck1117, 2025-01-27:
> Not observed on my master.

have you changed heater PID parameters?

dron0gus, 2025-01-27:
> have you changed heater PID parameters?

Nope. PID parameters are stock.

dron0gus, 2025-01-27:
Ok, seems you lost conversion from mS to S in https://github.com/mck1117/wideband/commit/7954cbd5a441a859e804c328519e33b7654a4c1d .

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

rusefillc, 2025-01-27:
@mck1117 @dron0gus any chance for a defect if this turns to be a legit new defect?

dron0gus, 2025-01-27:
https://github.com/mck1117/wideband/pull/326

dron0gus, 2025-01-27:
> Ok, seems you lost conversion from mS to S in [7954cbd](https://github.com/mck1117/wideband/commit/7954cbd5a441a859e804c328519e33b7654a4c1d) .
>
> 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

This is a "good" oscillations. After fix. This is damping oscillations. Not sure how fast we expect it to become straight line, but look much better.

mck1117, 2025-01-27:
fixed in 2c1f1acd9f6e5b3b8da9d36d51acf0b44f415393

Closed 2025-01-27.

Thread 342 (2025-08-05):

Should we care about Ipump driver duty?

dron0gus, 2025-08-05:
Poor tuning. Used LSU4.9 sensor.
When going to lean region AFR often drops to zero. This is because of valid flag. Valid flag is reset because of following check:
https://github.com/mck1117/wideband/blob/b4cfb5141303dd054c2df5cd8f4ff48ad7bf07d3/firmware/can.cpp#L180
Do we actually need to care about pump duty if we have feedback from current sensor?
Should we at least expand valid range? On graph below pumpDuty is 8 when pump is considered slammed into stop. Max AFR is 19.117.

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

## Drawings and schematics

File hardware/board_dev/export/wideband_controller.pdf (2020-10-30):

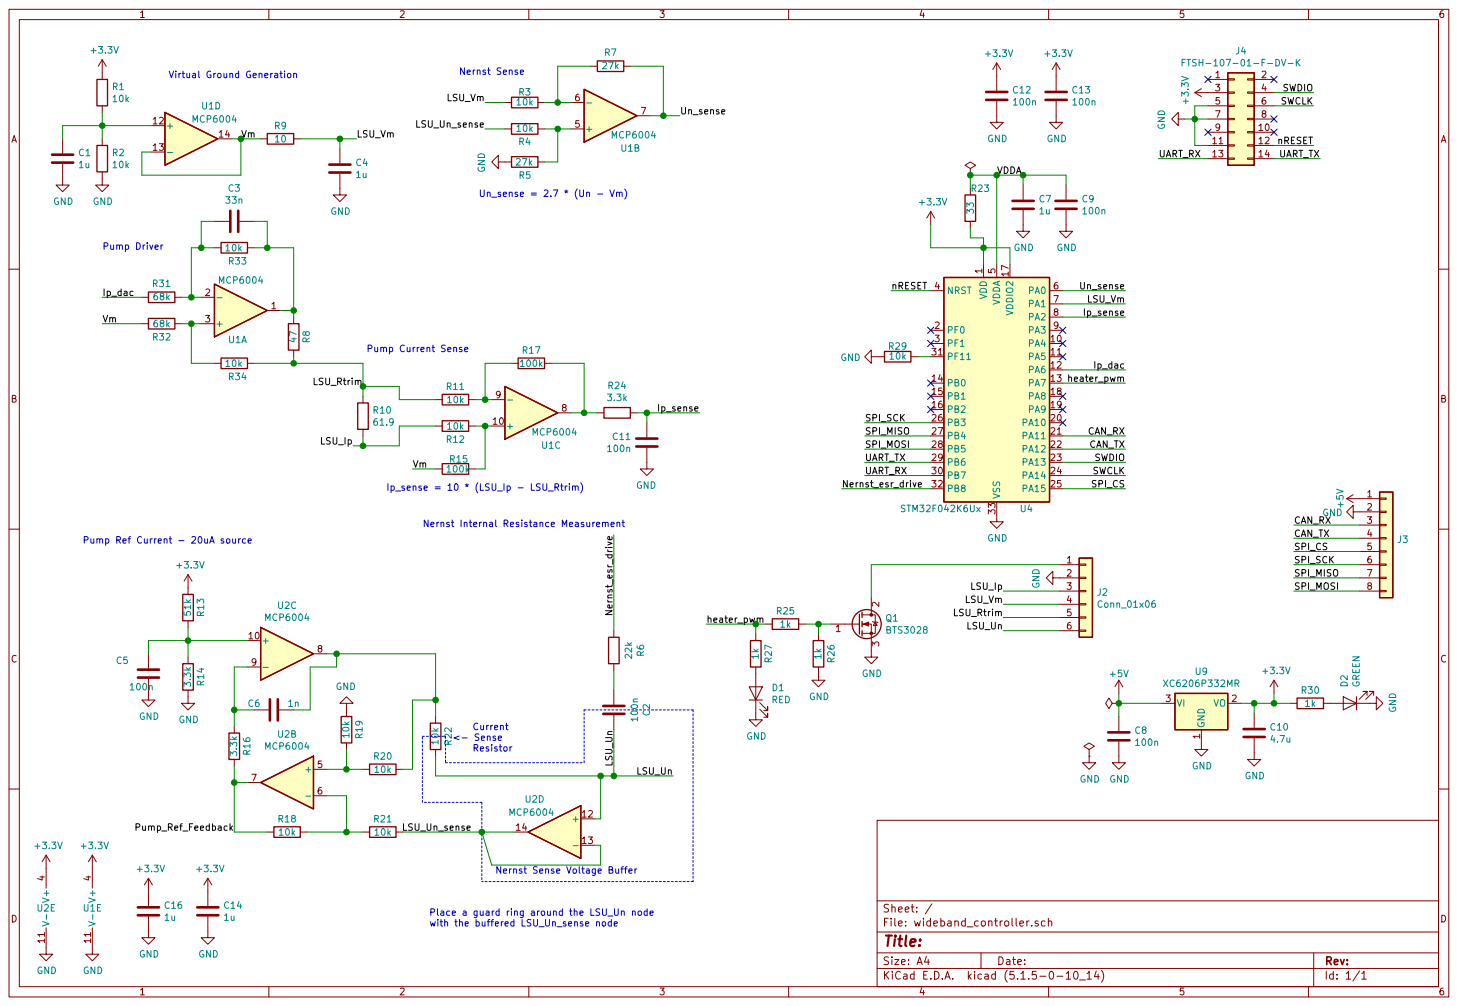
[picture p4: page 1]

Pump Current Sense Nernst Sense

Resistor Place a guard ring around the LSU_Un node with the buffered LSU_Un_sense node

Nernst Sense Voltage Buffer

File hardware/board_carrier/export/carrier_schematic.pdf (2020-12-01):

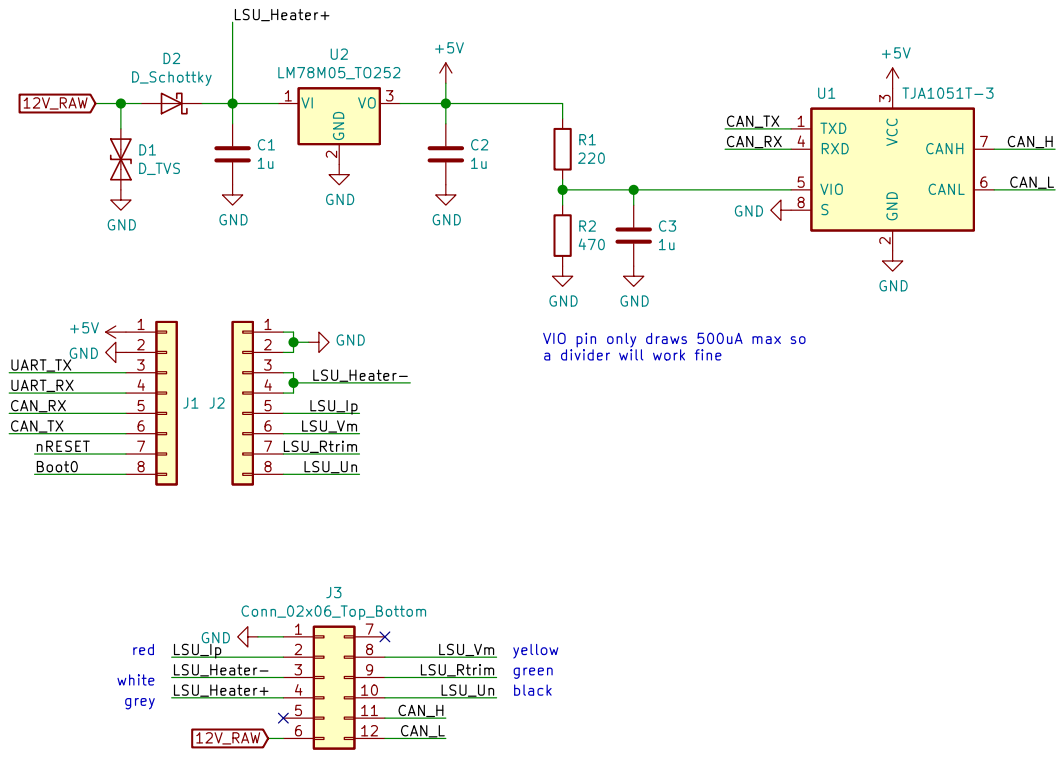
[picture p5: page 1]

3 RXD 4 VIO 5 CANL 6 CANH 7 S

a divider will work fine

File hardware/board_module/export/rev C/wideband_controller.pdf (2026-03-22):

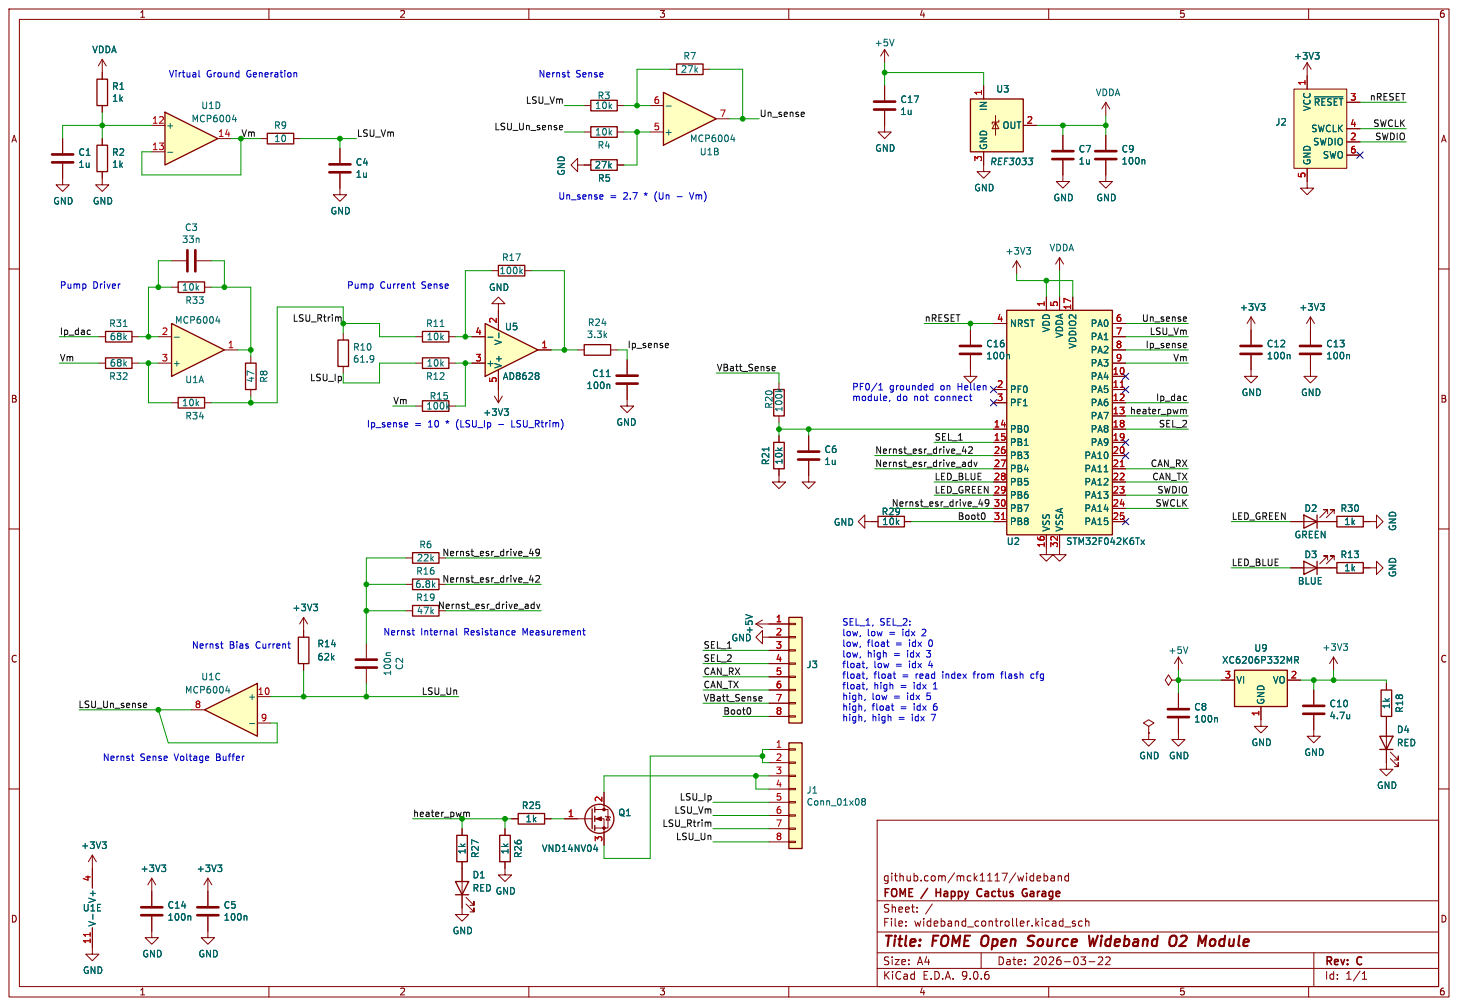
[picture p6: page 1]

5 ~{RESET}3 SWCLK 4 SWDIO 2 SWO C9 6

5 ~{RESET}3 SWCLK 4 SWDIO 2 SWO 6

low, low = idx 2
low, float = idx 0
low, high = idx 3
float, low = idx 4
float, float = read index from flash cfg
float, high = idx 1
high, low = idx 5
high, float = idx 6
high, high = idx 7

Id: 1/1 Title: FOME Open Source Wideband O2 Module

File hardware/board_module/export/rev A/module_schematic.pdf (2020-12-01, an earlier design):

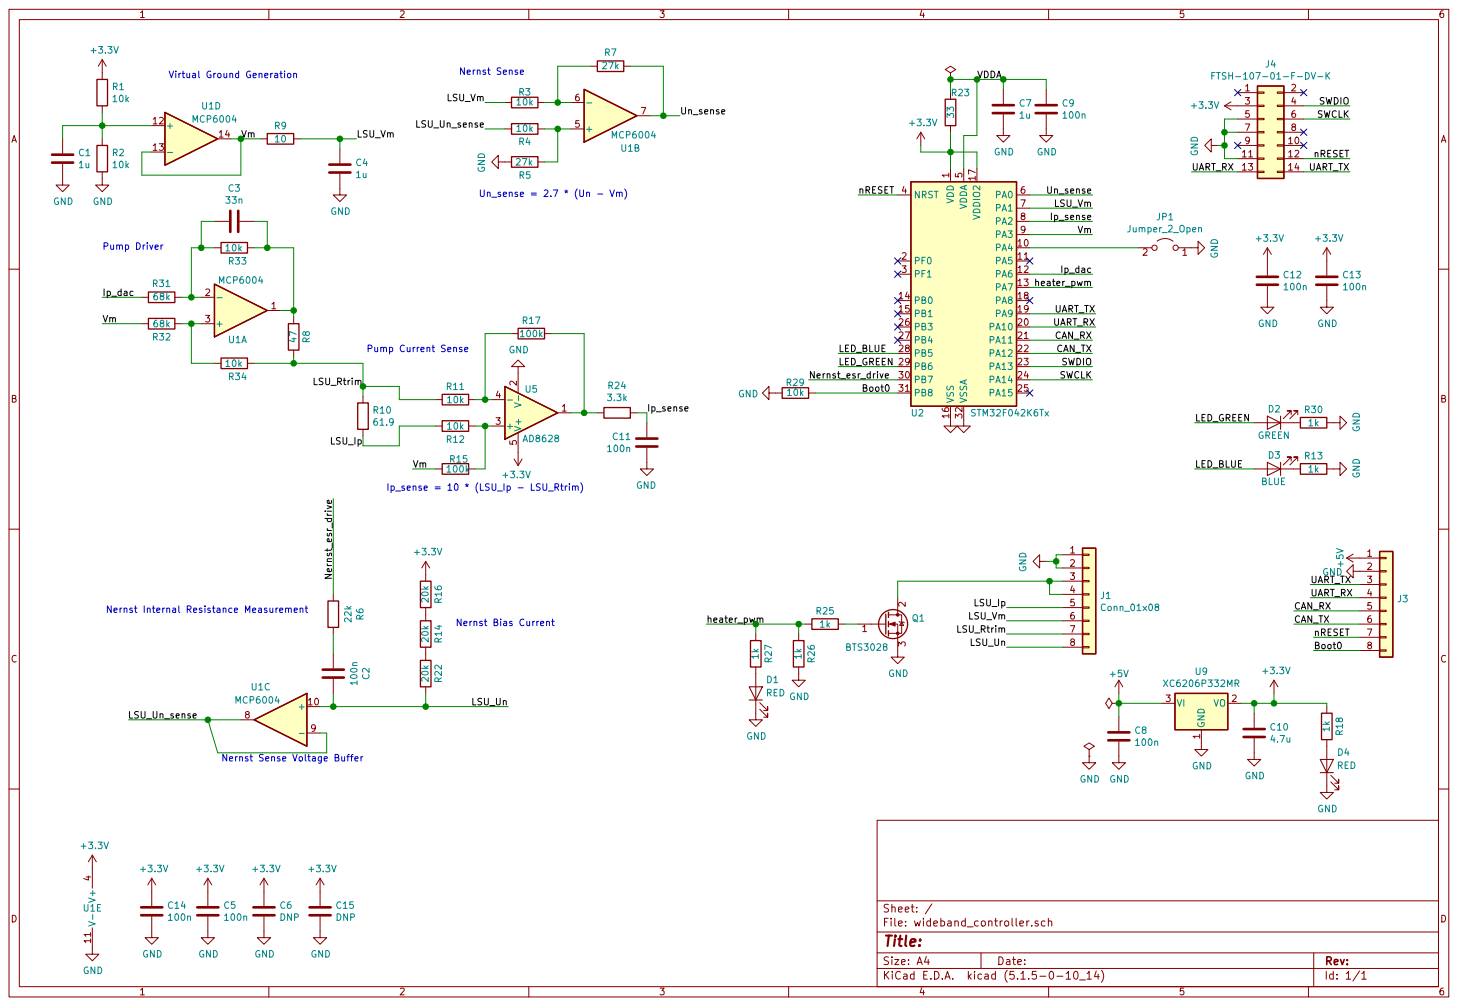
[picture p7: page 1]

Nernst Sense Un_sense = 2.7 * (Un - Vm)

1 PA4 10 PA5 11 PA6 12 PA7 13 PB0 14 PB1 15 VSS 16 VDDIO2 17 PA8 18 PA9 19 PF0 2 PA10 20 PA11 21 PA12 22 PA13 23 PA14 24 PA15 25 PB3 26 PB4 27 PB5 28 PB6 29 PF1 3 PB7 30 PB8 31 VSSA 32 NRST 4 VDDA

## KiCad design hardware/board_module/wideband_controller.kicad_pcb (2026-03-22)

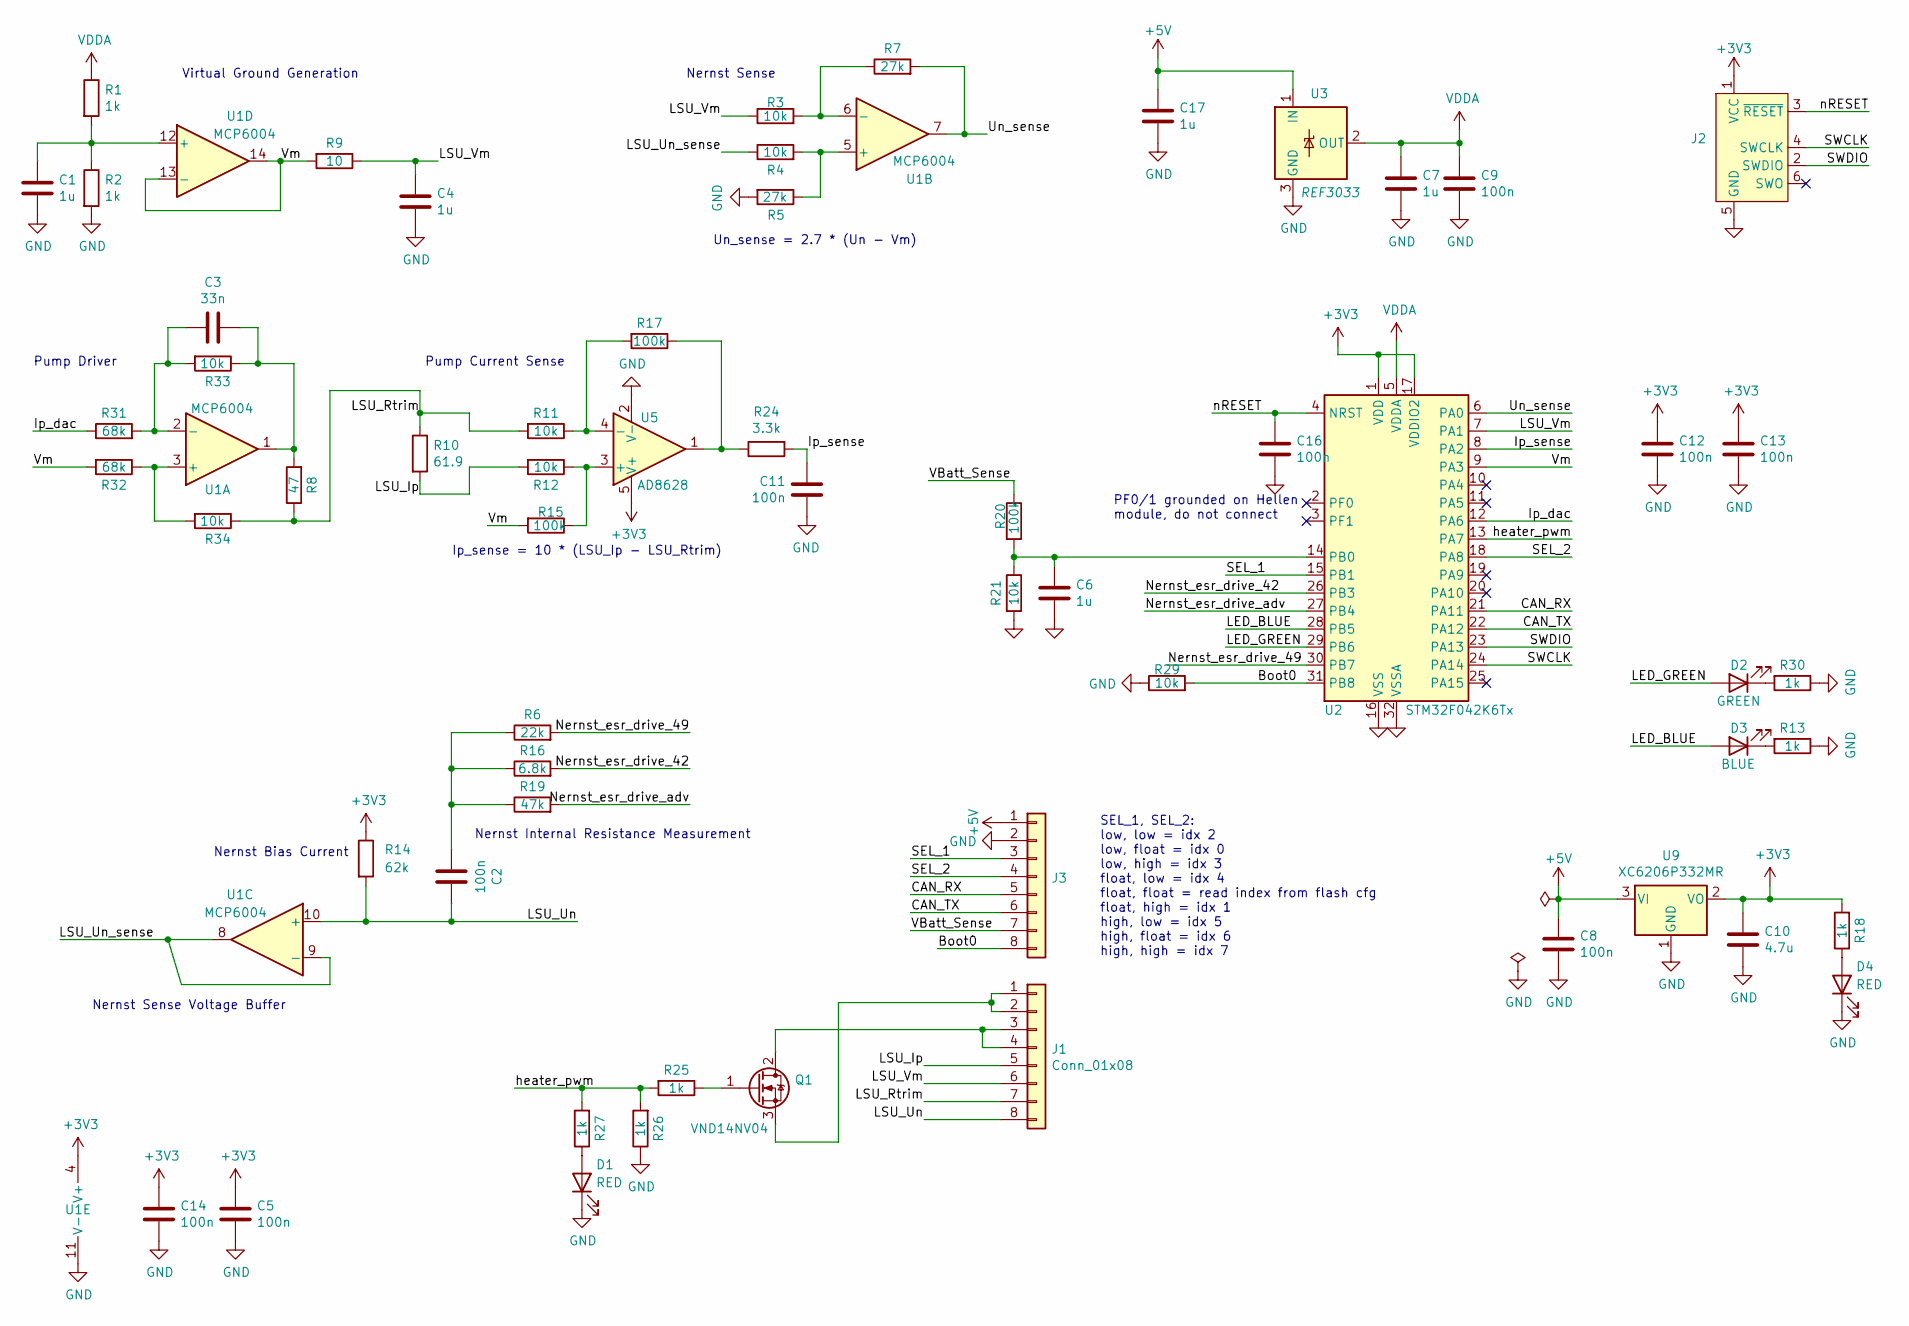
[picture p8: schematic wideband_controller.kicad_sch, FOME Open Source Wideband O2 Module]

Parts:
C1, C4, C6, C7, C17: 1u; C_0402_1005Metric; LCSC C52923
C2, C5, C8, C9, C11, C12, C13, C14, C16: 100n; C_0402_1005Metric; LCSC C1525
C3: 33n; C_0402_1005Metric; LCSC C1585
C10: 4.7u; C_0603_1608Metric; LCSC C19666
D1, D4: RED; LED_0603_1608Metric; LCSC C2286
D2: GREEN; LED_0603_1608Metric; LCSC C12624
D3: BLUE; LED_0603_1608Metric; LCSC C2288
J1, J3: Conn_01x08; PinHeader_1x08_P2.54mm_Vertical; LCSC C32713274
J2: Conn_ARM_SWD_TagConnect_TC2030; Tag-Connect_TC2030-IDC-NL_2x03_P1.27mm_Vertical
Q1: VND14NV04; TO-252-2; LCSC C2649436
R1, R2, R13, R18, R25, R26, R27, R30: 1k; R_0402_1005Metric; LCSC C11702
R3, R4, R11, R12, R21, R29, R33, R34: 10k; R_0402_1005Metric; LCSC C25744
R5, R7: 27k; R_0402_1005Metric; LCSC C25771
R6: 22k; R_0402_1005Metric; LCSC C25768
R8: 47; R_0402_1005Metric; LCSC C25118
R9: 10; R_0402_1005Metric; LCSC C25077
R10: 61.9; R_0603_1608Metric; LCSC C23092
R14: 62k; R_0603_1608Metric; LCSC C23221
R15, R17, R20: 100k; R_0402_1005Metric; LCSC C25741
R16: 6.8k; R_0402_1005Metric; LCSC C25917
R19: 47k; R_0402_1005Metric; LCSC C25792
R24: 3.3k; R_0402_1005Metric; LCSC C25890
R31, R32: 68k; R_0402_1005Metric; LCSC C36871
U1: MCP6004; TSSOP-14_4.4x5mm_P0.65mm; LCSC C50282
U2: STM32F042K6Tx; LQFP-32_7x7mm_P0.8mm; LCSC C69216
U3: REF3033; SOT-23; LCSC C36658
U5: AD8628; TSOT-23-5; LCSC C29309
U9: XC6206P332MR; SOT-23; LCSC C5446

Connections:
+3V3: C5.1, C10.1, C12.1, C13.1, C14.1, J2.1 (VCC), R14.1, R18.2, U1.4 (V+), U2.1 (VDD), U2.17 (VDDIO2), U5.5 (V+), U9.2 (VO)
+5V: C8.1, C17.1, J3.1, U3.1 (IN), U9.3 (VI)
/Boot0: J3.8, R29.2, U2.31 (PB8)
/CAN_RX: J3.5, U2.21 (PA11)
/CAN_TX: J3.6, U2.22 (PA12)
/Ip_dac: R31.1, U2.12 (PA6)
/Ip_sense: C11.1, R24.2, U2.8 (PA2)
/LED_BLUE: D3.2 (A), U2.28 (PB5)
/LED_GREEN: D2.2 (A), U2.29 (PB6)
/LSU_Ip: J1.5, R10.2, R12.2
/LSU_Rtrim: J1.7, R8.1, R10.1, R11.2, R34.1
/LSU_Un: C2.1, J1.8, R14.2, U1.10 (+)
/LSU_Un_sense: R4.1, U1.8, U1.9 (-)
/LSU_Vm: C4.1, J1.6, R3.1, R9.1, U2.7 (PA1)
/Nernst_esr_drive_42: R16.2, U2.26 (PB3)
/Nernst_esr_drive_49: R6.2, U2.30 (PB7)
/Nernst_esr_drive_adv: R19.2, U2.27 (PB4)
/SEL_1: J3.3, U2.15 (PB1)
/SEL_2: J3.4, U2.18 (PA8)
/SWCLK: J2.4 (SWCLK), U2.24 (PA14)
/SWDIO: J2.2 (SWDIO), U2.23 (PA13)
/Un_sense: R7.2, U1.7, U2.6 (PA0)
/VBatt_Sense: J3.7, R20.1
/Vm: R9.2, R15.2, R32.2, U1.13 (-), U1.14, U2.9 (PA3)
/heater_pwm: R25.2, R26.2, R27.2, U2.13 (PA7)
/nRESET: C16.1, J2.3 (~RESET), U2.4 (NRST)
GND: C1.2, C4.2, C5.2, C6.2, C7.2, C8.2, C9.2, C10.2, C11.2, C12.2, C13.2, C14.2, C16.2, C17.2, D1.1 (K), D4.1 (K), J2.5 (GND), J3.2, R2.2, R5.2, R13.1, R21.2, R26.1, R29.1, R30.1, U1.11 (V-), U2.16 (VSS), U2.32 (VSSA), U3.3 (GND), U5.2 (V-), U9.1 (GND)
unnamed: C2.2, R6.1, R16.1, R19.1
unnamed: C3.1, R8.2, R33.1, U1.1
unnamed: D1.2 (A), R27.1
unnamed: D2.1 (K), R30.2
unnamed: D3.1 (K), R13.2
unnamed: D4.2 (A), R18.1
unnamed: J1.1, J1.2, Q1.3 (S)
unnamed: J1.3, J1.4, Q1.2 (D)
unnamed: Q1.1 (G), R25.1
unnamed: R17.1, R24.1, U5.1
unnamed: R32.1, R34.2, U1.3 (+)
unnamed: C3.2, R31.2, R33.2, U1.2 (-)
unnamed: R4.2, R5.1, U1.5 (+)
unnamed: R3.2, R7.1, U1.6 (-)
unnamed: C1.1, R1.2, R2.1, U1.12 (+)
unnamed: C6.1, R20.2, R21.1, U2.14 (PB0)
unnamed: R12.1, R15.1, U5.3 (+)
unnamed: R11.1, R17.2, U5.4 (-)
VDDA: C7.1, C9.1, R1.1, U2.5 (VDDA), U3.2 (OUT)

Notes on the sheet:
Un_sense = 2.7 * (Un - Vm)
Nernst Internal Resistance Measurement
Pump Driver
Nernst Sense Voltage Buffer
PF0/1 grounded on Hellen module, do not connect
Nernst Bias Current
Ip_sense = 10 * (LSU_Ip - LSU_Rtrim)
Virtual Ground Generation
Nernst Sense
Pump Current Sense
SEL_1, SEL_2: low, low = idx 2 low, float = idx 0 low, high = idx 3 float, low = idx 4 float, float = read index from flash cfg float, high = idx 1 high, low = idx 5 high, float = idx 6 high, high = idx 7

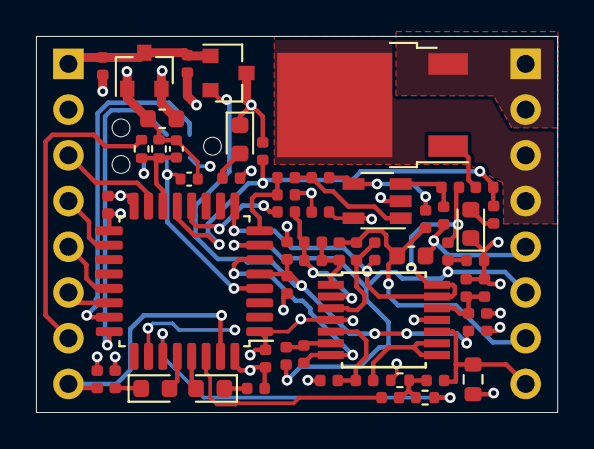
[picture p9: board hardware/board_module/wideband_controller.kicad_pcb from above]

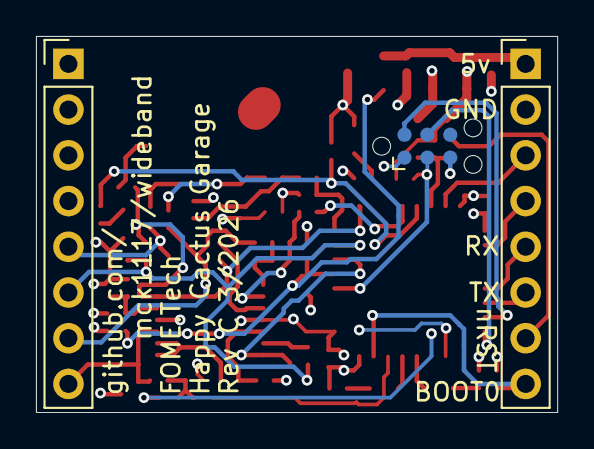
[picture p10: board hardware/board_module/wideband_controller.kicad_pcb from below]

Board: 4 copper layers, 29.0 x 20.9 mm, 60 parts (3 on the bottom side), 46 nets.

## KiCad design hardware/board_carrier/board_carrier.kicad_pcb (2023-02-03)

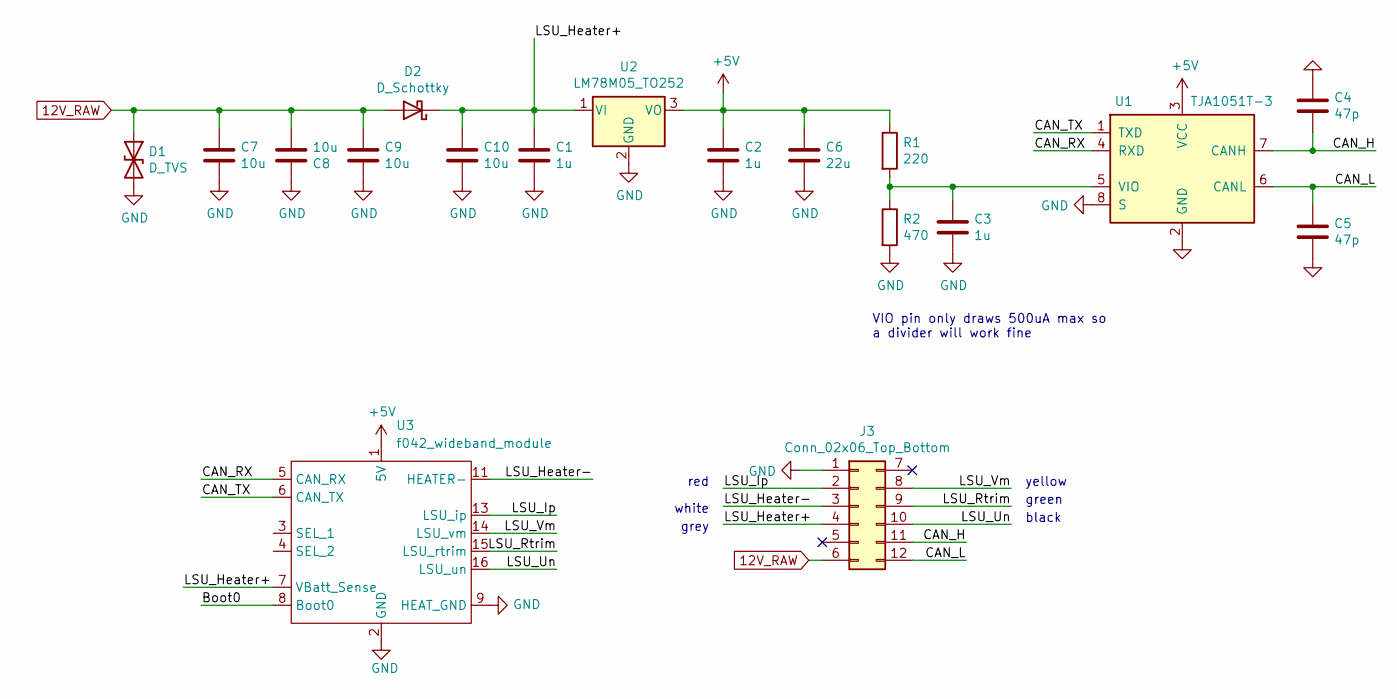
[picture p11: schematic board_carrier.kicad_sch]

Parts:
C1, C2, C3: 1u; C_0603_1608Metric; LCSC C15849
C4, C5: 47p; C_0402_1005Metric; LCSC C1567
C6: 22u; C_0805_2012Metric; LCSC C45783
C7, C8, C9, C10: 10u; C_1206_3216Metric; LCSC C13585
D1: D_TVS; D_SMC; LCSC C151279
D2: D_Schottky; D_SMA; LCSC C22452
J3: Conn_02x06_Top_Bottom; mx120g-12
R1: 220; R_0603_1608Metric; LCSC C22962
R2: 470; R_0603_1608Metric; LCSC C23179
U1: TJA1051T-3; SOIC-8_3.9x4.9mm_P1.27mm; LCSC C38695
U2: LM78M05_TO252; TO-252-2; LCSC C58069
U3: f042_wideband_module

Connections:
12V_RAW: C7.1, C8.2, C9.1, D1.1 (A1), D2.2 (A), J3.6
+5V: C2.1, C6.1, R1.1, U1.3 (VCC), U2.3 (VO), U3.1 (5V)
/Boot0: U3.8 (Boot0)
/CAN_H: C4.2, J3.11, U1.7 (CANH)
/CAN_L: C5.1, J3.12, U1.6 (CANL)
/CAN_RX: U1.4 (RXD), U3.5 (CAN_RX)
/CAN_TX: U1.1 (TXD), U3.6 (CAN_TX)
/LSU_Heater+: C1.1, C10.1, D2.1 (K), J3.4, U2.1 (VI), U3.7 (VBatt_Sense)
/LSU_Heater-: J3.3, U3.11 (HEATER-), U3.12 (HEATER-)
/LSU_Ip: J3.2, U3.13 (LSU_ip)
/LSU_Rtrim: J3.9, U3.15 (LSU_rtrim)
/LSU_Un: J3.10, U3.16 (LSU_un)
/LSU_Vm: J3.8, U3.14 (LSU_vm)
GND: C1.2, C2.2, C3.2, C4.1, C5.2, C6.2, C7.2, C8.1, C9.2, C10.2, D1.2 (A2), J3.1, R2.2, U1.2 (GND), U1.8 (S), U2.2 (GND), U3.2 (GND), U3.9 (HEAT_GND), U3.10 (HEAT_GND2)
unnamed: C3.1, R1.2, R2.1, U1.5 (VIO)

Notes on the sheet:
yellow
green
red
black
white
VIO pin only draws 500uA max so a divider will work fine
grey

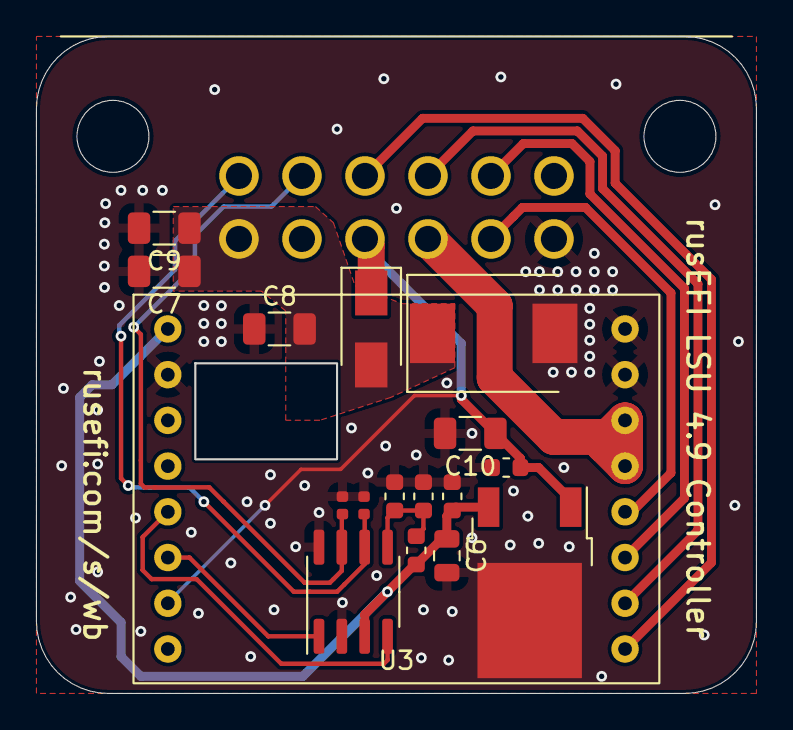
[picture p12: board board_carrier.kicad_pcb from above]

Board: 2 copper layers, 40.0 x 36.5 mm, 18 parts (0 on the bottom side), 14 nets.

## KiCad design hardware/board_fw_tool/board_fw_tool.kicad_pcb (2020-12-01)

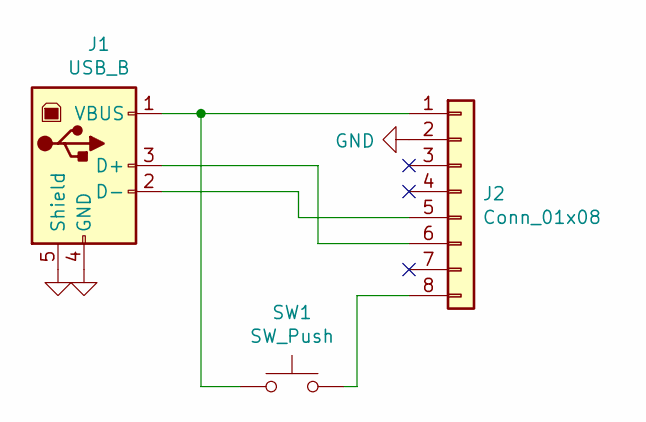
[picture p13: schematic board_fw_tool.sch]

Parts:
J1: USB_B; USB_B_TE_5787834_Vertical
J2: Conn_01x08; PinSocket_1x08_P2.54mm_Vertical
SW1: SW_Push; SW_PUSH_6mm

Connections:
GND: J1.4 (GND), J1.5 (Shield), J2.2
unnamed: J1.1 (VBUS), J2.1, SW1.1
unnamed: J1.2 (D-), J2.5
unnamed: J1.3 (D+), J2.6
unnamed: J2.8, SW1.2

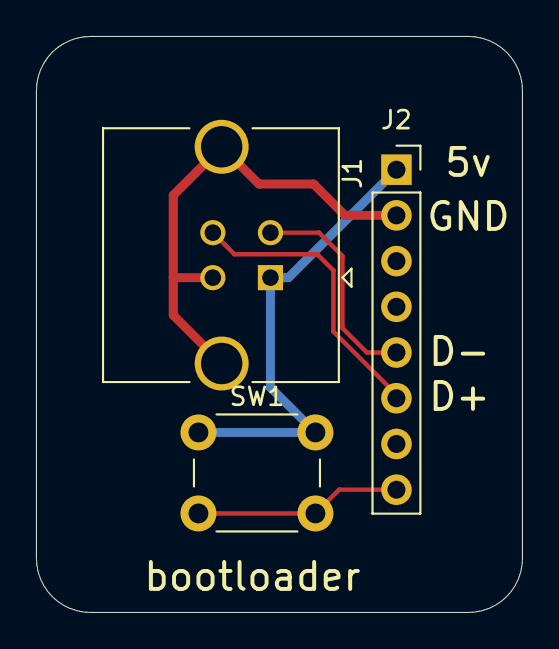
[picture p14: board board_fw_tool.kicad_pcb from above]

Board: 2 copper layers, 27.0 x 32.0 mm, 3 parts (0 on the bottom side), 5 nets.

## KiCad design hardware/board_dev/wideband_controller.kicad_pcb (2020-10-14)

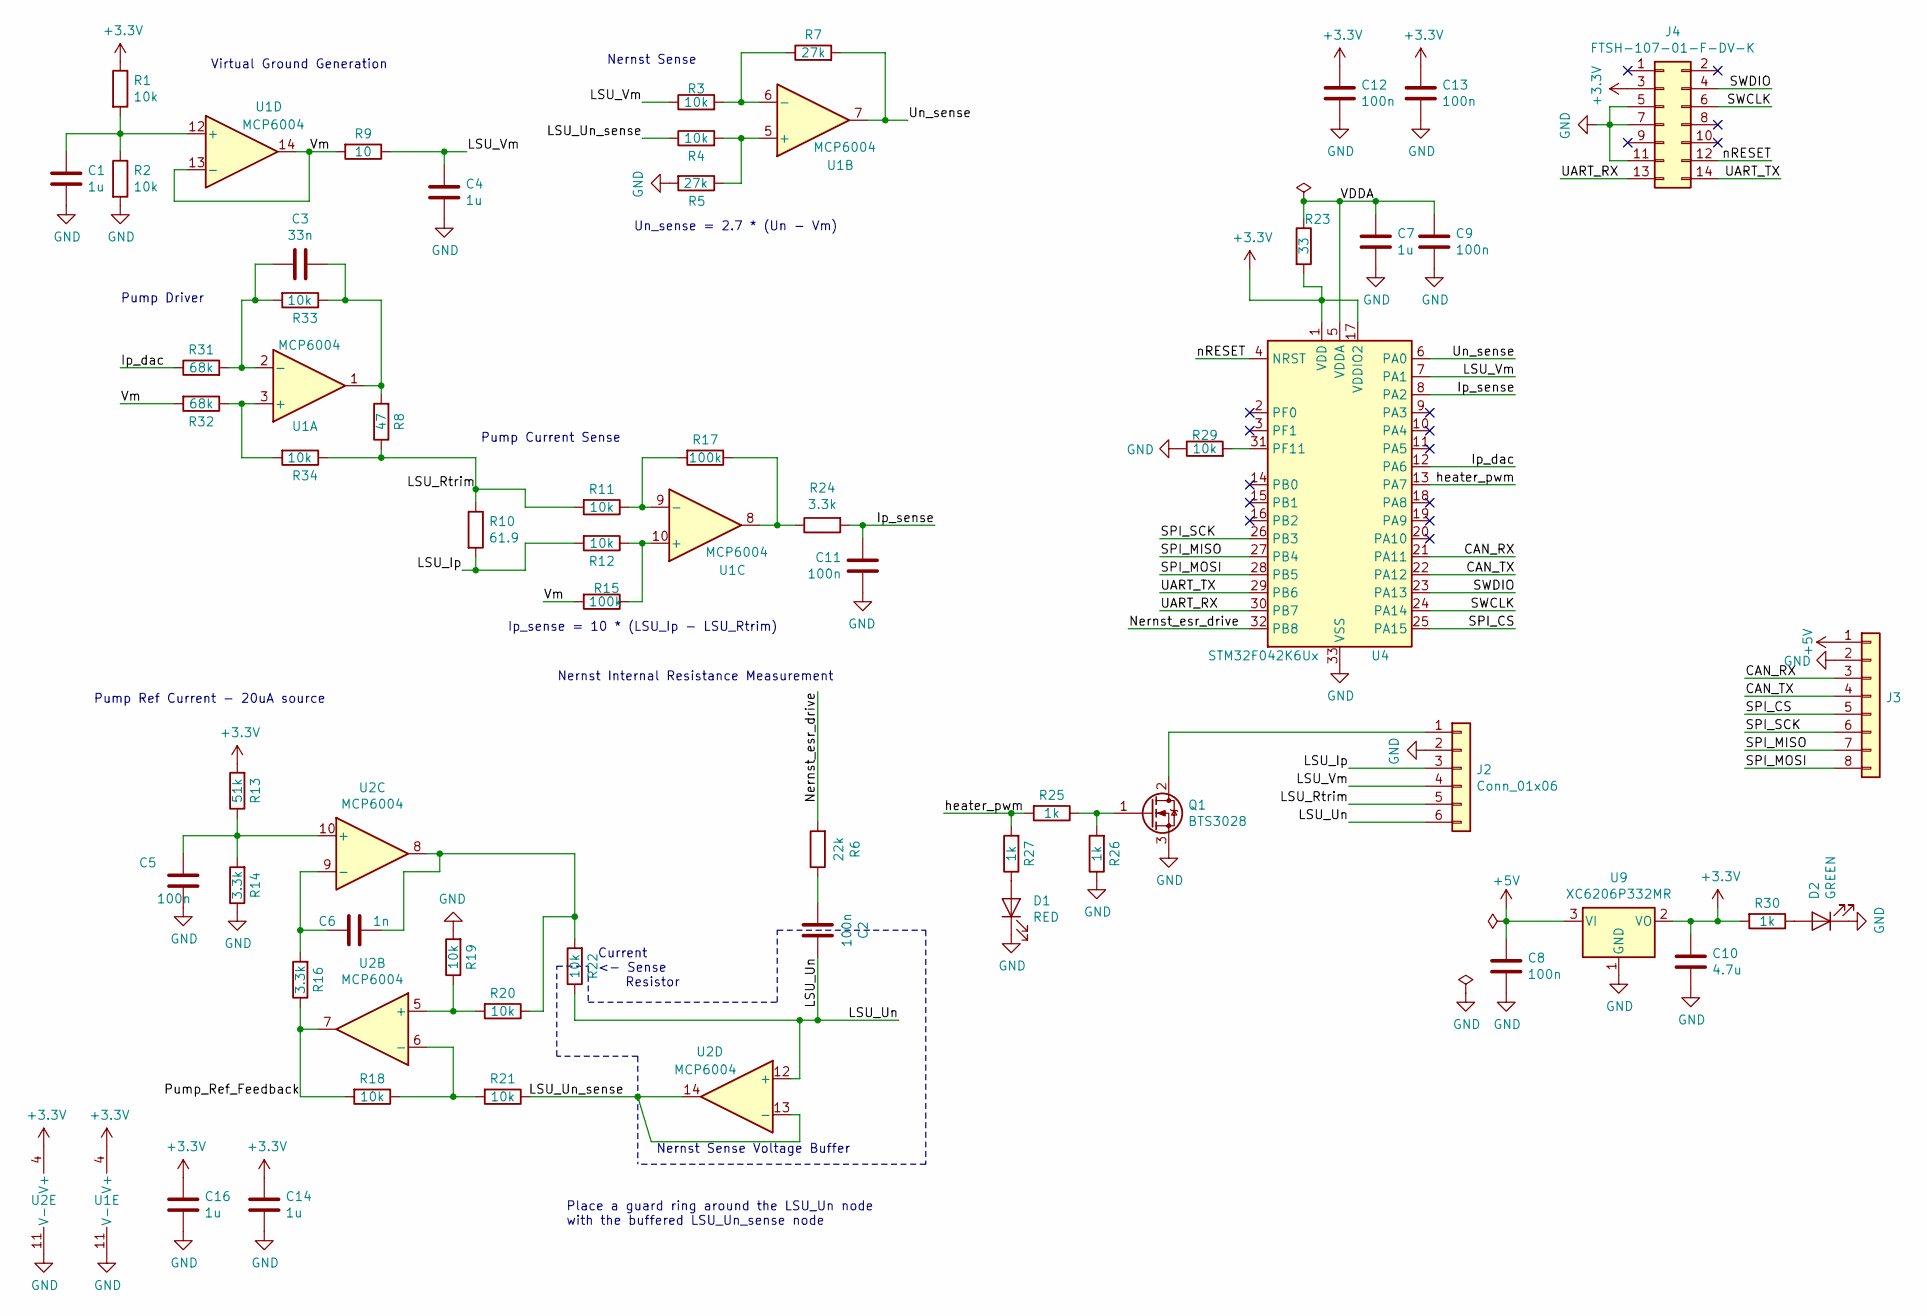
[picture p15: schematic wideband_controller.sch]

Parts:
C1, C4, C7, C14, C16: 1u; C_0402_1005Metric; LCSC C52923
C2: 100n; C_0603_1608Metric; LCSC C14663
C3: 33n; C_0402_1005Metric; LCSC C1585
C5, C8, C9, C11, C12, C13: 100n; C_0402_1005Metric; LCSC C1525
C6: 1n; C_0402_1005Metric; LCSC C1523
C10: 4.7u; C_0603_1608Metric; LCSC C19666
D1: RED; LED_0603_1608Metric; LCSC C2286
D2: GREEN; LED_0603_1608Metric; LCSC C72043
J2: Conn_01x06; PhoenixContact_MSTBVA_2,5_6-G-5,08_1x06_P5.08mm_Vertical
J3: Conn_01x08; PinHeader_1x08_P2.54mm_Vertical
J4: FTSH-107-01-F-DV-K; PinHeader_2x07_P1.27mm_Vertical_SMD
Q1: BTS3028; TO-252-2; LCSC C112639
R1, R2, R3, R4, R11, R12, R18, R19, R20, R21, R29, R33, R34: 10k; R_0402_1005Metric; LCSC C25744
R5, R7: 27k; R_0402_1005Metric; LCSC C25771
R6: 22k; R_0402_1005Metric; LCSC C25768
R8: 47; R_0402_1005Metric; LCSC C25118
R9: 10; R_0402_1005Metric; LCSC C25077
R10: 61.9; R_0603_1608Metric; LCSC C23092
R13: 51k; R_0402_1005Metric; LCSC C25794
R14, R16, R24: 3.3k; R_0402_1005Metric; LCSC C25890
R15, R17: 100k; R_0402_1005Metric; LCSC C25741
R22: 10k; R_0603_1608Metric; LCSC C25804
R23: 33; R_0402_1005Metric; LCSC C25105
R25, R26, R27, R30: 1k; R_0402_1005Metric; LCSC C11702
R31, R32: 68k; R_0402_1005Metric; LCSC C36871
U1, U2: MCP6004; TSSOP-14_4.4x5mm_P0.65mm; LCSC C50282
U4: STM32F042K6Ux; QFN-32-1EP_5x5mm_P0.5mm_EP3.45x3.45mm; LCSC C110616
U9: XC6206P332MR; SOT-23; LCSC C5446

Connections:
+3V3: C10.1, C12.1, C13.1, C14.1, C16.1, J4.3, R1.1, R13.2, R23.2, R30.2, U1.4 (V+), U2.4 (V+), U4.1 (VDD), U4.17 (VDDIO2), U9.2 (VO)
+5V: C8.1, J3.1, U9.3 (VI)
/CAN_RX: J3.3, U4.21 (PA11)
/CAN_TX: J3.4, U4.22 (PA12)
/Ip_dac: R31.1, U4.12 (PA6)
/Ip_sense: C11.1, R24.2, U4.8 (PA2)
/LSU_Ip: J2.3, R10.2, R12.2
/LSU_Rtrim: J2.5, R8.1, R10.1, R11.2, R34.1
/LSU_Un: C2.1, J2.6, R22.1, U2.12 (+)
/LSU_Un_sense: R4.1, R21.1, U2.13 (-), U2.14
/LSU_Vm: C4.1, J2.4, R3.1, R9.1, U4.7 (PA1)
/Nernst_esr_drive: R6.2, U4.32 (PB8)
/Pump_Ref_Feedback: R16.1, R18.2, U2.7
/SPI_CS: J3.5, U4.25 (PA15)
/SPI_MISO: J3.7, U4.27 (PB4)
/SPI_MOSI: J3.8, U4.28 (PB5)
/SPI_SCK: J3.6, U4.26 (PB3)
/SWCLK: J4.6, U4.24 (PA14)
/SWDIO: J4.4, U4.23 (PA13)
/UART_RX: J4.13, U4.30 (PB7)
/UART_TX: J4.14, U4.29 (PB6)
/Un_sense: R7.2, U1.7, U4.6 (PA0)
/VDDA: C7.1, C9.1, R23.1, U4.5 (VDDA)
/Vm: R9.2, R15.2, R32.2, U1.13 (-), U1.14
/heater_pwm: R25.2, R27.2, U4.13 (PA7)
/nRESET: J4.12, U4.4 (NRST)
GND: C1.2, C4.2, C5.2, C7.2, C8.2, C9.2, C10.2, C11.2, C12.2, C13.2, C14.2, C16.2, D1.1 (K), D2.1 (K), J2.2, J3.2, J4.5, J4.7, J4.11, Q1.3 (S), R2.2, R5.2, R14.1, R19.2, R26.1, R29.1, U1.11 (V-), U2.11 (V-), U4.33 (VSS), U9.1 (GND)
unnamed: C1.1, R1.2, R2.1, U1.12 (+)
unnamed: C2.2, R6.1
unnamed: C3.1, R8.2, R33.1, U1.1
unnamed: C3.2, R31.2, R33.2, U1.2 (-)
unnamed: C5.1, R13.1, R14.2, U2.10 (+)
unnamed: C6.1, R20.1, R22.2, U2.8
unnamed: C6.2, R16.2, U2.9 (-)
unnamed: D1.2 (A), R27.1
unnamed: D2.2 (A), R30.1
unnamed: J2.1, Q1.2 (D)
unnamed: Q1.1 (G), R25.1, R26.2
unnamed: R3.2, R7.1, U1.6 (-)
unnamed: R4.2, R5.1, U1.5 (+)
unnamed: R11.1, R17.2, U1.9 (-)
unnamed: R12.1, R15.1, U1.10 (+)
unnamed: R17.1, R24.1, U1.8
unnamed: R18.1, R21.2, U2.6 (-)
unnamed: R19.1, R20.2, U2.5 (+)
unnamed: R29.2, U4.31 (PF11)
unnamed: R32.1, R34.2, U1.3 (+)

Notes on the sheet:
Pump Current Sense
Virtual Ground Generation
Nernst Internal Resistance Measurement
Pump Ref Current - 20uA source
Pump Driver
Nernst Sense
Un_sense = 2.7 * (Un - Vm)
Ip_sense = 10 * (LSU_Ip - LSU_Rtrim)
Nernst Sense Voltage Buffer
Current <- Sense Resistor
Place a guard ring around the LSU_Un node with the buffered LSU_Un_sense node

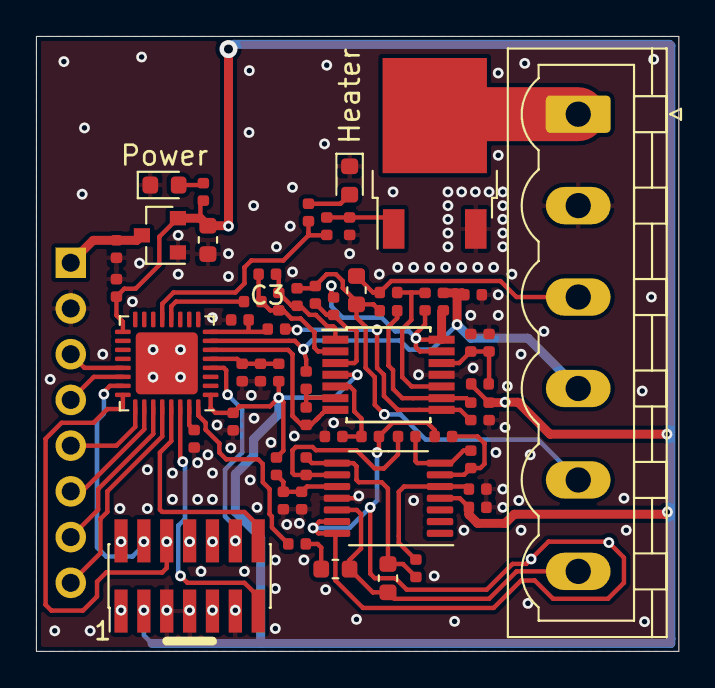
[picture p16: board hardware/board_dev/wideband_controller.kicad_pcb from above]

Board: 2 copper layers, 35.7 x 34.2 mm, 58 parts (1 on the bottom side), 47 nets.

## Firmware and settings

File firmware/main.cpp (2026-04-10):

#include "ch.h"
#include "hal.h"

#include "can.h"
#include "status.h"
#include "heater_control.h"
#include "pump_control.h"
#include "pump_dac.h"
#include "sampling.h"
#include "uart.h"
#include "io_pins.h"
#include "auxout.h"
#include "max3185x.h"
#include "port.h"
#include "tunerstudio.h"
#include "indication.h"

#include "wideband_config.h"

#include <cstring>

using namespace wbo;

/*
 * Application entry point.
 */
int main()
{
    halInit();
    chSysInit();

    // Load configuration
    InitConfiguration();

    // Fire up all of our threads
    StartSampling();
    InitPumpDac();
    StartHeaterControl();
    StartPumpControl();
    InitAuxDac();

#if TS_ENABLED
    startTunerStudioConnectivity();
#endif

    InitCan();
    InitUart();
    InitIndication();

#if (EGT_CHANNELS > 0)
    StartEgt();
#endif

    while (true)
    {
#ifdef ADVANCED_INDICATION
        /* NOP nap */
        chThdSleepMilliseconds(1000);
#else
        /* TODO: show error for all AFR channels */
        /* TODO: show EGT errors */
        auto status = GetCurrentStatus(0);

        if (status < Status::SensorDidntHeat)
        {
            // blue is off
            palClearPad(LED_BLUE_PORT, LED_BLUE_PIN);

            // Green is blinking
            palTogglePad(LED_GREEN_PORT, LED_GREEN_PIN);

            // Slow blink if closed loop, fast if not
            chThdSleepMilliseconds(status == Status::RunningClosedLoop ? 700 : 50);
        }
        else
        {
            // green is off
            palClearPad(LED_GREEN_PORT, LED_GREEN_PIN);

            // Blink out the error code
            for (uint8_t i = 0; i < 2 * static_cast<uint8_t>(status); i++)
            {
                // Blue is blinking
                palTogglePad(LED_BLUE_PORT, LED_BLUE_PIN);

                // fast blink
                chThdSleepMilliseconds(300);
            }

            chThdSleepMilliseconds(2000);
        }
#endif
    }
}

typedef enum
{
    Reset = 1,
    NMI = 2,
    HardFault = 3,
    MemManage = 4,
    BusFault = 5,
    UsageFault = 6,
} FaultType;

#define bkpt() __asm volatile("BKPT #0\n")

extern "C" void HardFault_Handler_C(void* sp)
{
    // Copy to local variables (not pointers) to allow GDB "i loc" to directly show the info
    // Get thread context. Contains main registers including PC and LR
    struct port_extctx ctx;
    memcpy(&ctx, sp, sizeof(struct port_extctx));

    // Interrupt status register: Which interrupt have we encountered, e.g. HardFault?
    FaultType faultType = (FaultType)__get_IPSR();
    (void)faultType;
#if (__CORTEX_M > 0)
    // For HardFault/BusFault this is the address that was accessed causing the error
    uint32_t faultAddress = SCB->BFAR;

    // Flags about hardfault / busfault
    // See http://infocenter.arm.com/help/index.jsp?topic=/com.arm.doc.dui0552a/Cihdjcfc.html for reference
    bool isFaultPrecise = ((SCB->CFSR >> SCB_CFSR_BUSFAULTSR_Pos) & (1 << 1) ? true : false);
    bool isFaultImprecise = ((SCB->CFSR >> SCB_CFSR_BUSFAULTSR_Pos) & (1 << 2) ? true : false);
    bool isFaultOnUnstacking = ((SCB->CFSR >> SCB_CFSR_BUSFAULTSR_Pos) & (1 << 3) ? true : false);
    bool isFaultOnStacking = ((SCB->CFSR >> SCB_CFSR_BUSFAULTSR_Pos) & (1 << 4) ? true : false);
    bool isFaultAddressValid = ((SCB->CFSR >> SCB_CFSR_BUSFAULTSR_Pos) & (1 << 7) ? true : false);
    (void)faultAddress;
    (void)isFaultPrecise;
    (void)isFaultImprecise;
    (void)isFaultOnUnstacking;
    (void)isFaultOnStacking;
    (void)isFaultAddressValid;
#endif

    // Cause debugger to stop. Ignored if no debugger is attached
    bkpt();
    NVIC_SystemReset();
}

extern "C" void UsageFault_Handler_C(void* sp)
{
    // Copy to local variables (not pointers) to allow GDB "i loc" to directly show the info
    // Get thread context. Contains main registers including PC and LR
    struct port_extctx ctx;
    memcpy(&ctx, sp, sizeof(struct port_extctx));

    // Interrupt status register: Which interrupt have we encountered, e.g. HardFault?
    FaultType faultType = (FaultType)__get_IPSR();
    (void)faultType;
#if (__CORTEX_M > 0)
    // Flags about hardfault / busfault
    // See http://infocenter.arm.com/help/index.jsp?topic=/com.arm.doc.dui0552a/Cihdjcfc.html for reference
    bool isUndefinedInstructionFault = ((SCB->CFSR >> SCB_CFSR_USGFAULTSR_Pos) & (1 << 0) ? true : false);
    bool isEPSRUsageFault = ((SCB->CFSR >> SCB_CFSR_USGFAULTSR_Pos) & (1 << 1) ? true : false);
    bool isInvalidPCFault = ((SCB->CFSR >> SCB_CFSR_USGFAULTSR_Pos) & (1 << 2) ? true : false);
    bool isNoCoprocessorFault = ((SCB->CFSR >> SCB_CFSR_USGFAULTSR_Pos) & (1 << 3) ? true : false);
    bool isUnalignedAccessFault = ((SCB->CFSR >> SCB_CFSR_USGFAULTSR_Pos) & (1 << 8) ? true : false);
    bool isDivideByZeroFault = ((SCB->CFSR >> SCB_CFSR_USGFAULTSR_Pos) & (1 << 9) ? true : false);
    (void)isUndefinedInstructionFault;
    (void)isEPSRUsageFault;
    (void)isInvalidPCFault;
    (void)isNoCoprocessorFault;
    (void)isUnalignedAccessFault;
    (void)isDivideByZeroFault;
#endif

    bkpt();
    NVIC_SystemReset();
}

extern "C" void MemManage_Handler_C(void* sp)
{
    // Copy to local variables (not pointers) to allow GDB "i loc" to directly show the info
    // Get thread context. Contains main registers including PC and LR
    struct port_extctx ctx;
    memcpy(&ctx, sp, sizeof(struct port_extctx));

    // Interrupt status register: Which interrupt have we encountered, e.g. HardFault?
    FaultType faultType = (FaultType)__get_IPSR();
    (void)faultType;
#if (__CORTEX_M > 0)
    // For HardFault/BusFault this is the address that was accessed causing the error
    uint32_t faultAddress = SCB->MMFAR;
    (void)faultAddress;

    // Flags about hardfault / busfault
    // See http://infocenter.arm.com/help/index.jsp?topic=/com.arm.doc.dui0552a/Cihdjcfc.html for reference
    bool isInstructionAccessViolation = ((SCB->CFSR >> SCB_CFSR_MEMFAULTSR_Pos) & (1 << 0) ? true : false);
    bool isDataAccessViolation = ((SCB->CFSR >> SCB_CFSR_MEMFAULTSR_Pos) & (1 << 1) ? true : false);
    bool isExceptionUnstackingFault = ((SCB->CFSR >> SCB_CFSR_MEMFAULTSR_Pos) & (1 << 3) ? true : false);
    bool isExceptionStackingFault = ((SCB->CFSR >> SCB_CFSR_MEMFAULTSR_Pos) & (1 << 4) ? true : false);
    bool isFaultAddressValid = ((SCB->CFSR >> SCB_CFSR_MEMFAULTSR_Pos) & (1 << 7) ? true : false);
    (void)isInstructionAccessViolation;
    (void)isDataAccessViolation;
    (void)isExceptionUnstackingFault;
    (void)isExceptionStackingFault;
    (void)isFaultAddressValid;
#endif

    bkpt();
    NVIC_SystemReset();
}

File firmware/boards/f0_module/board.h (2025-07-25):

/*
    ChibiOS - Copyright (C) 2006..2020 Giovanni Di Sirio

    Licensed under the Apache License, Version 2.0 (the "License");
    you may not use this file except in compliance with the License.
    You may obtain a copy of the License at

        http://www.apache.org/licenses/LICENSE-2.0

    Unless required by applicable law or agreed to in writing, software
    distributed under the License is distributed on an "AS IS" BASIS,
    WITHOUT WARRANTIES OR CONDITIONS OF ANY KIND, either express or implied.
    See the License for the specific language governing permissions and
    limitations under the License.
*/

/*
 * This file has been automatically generated using ChibiStudio board
 * generator plugin. Do not edit manually.
 */

#ifndef BOARD_H
#define BOARD_H

/*===========================================================================*/
/* Driver constants.                                                         */
/*===========================================================================*/


/*
 * Board identifier.
 */
#define BOARD_NAME                  "rusEfi Wideband Controller"

/*
 * Board oscillators-related settings.
 * NOTE: LSE not fitted.
 * NOTE: HSE not fitted.
 */
#if !defined(STM32_LSECLK)
#define STM32_LSECLK                0U
#endif

#define STM32_LSEDRV                (3U << 3U)

#if !defined(STM32_HSECLK)
#define STM32_HSECLK                0U
#endif

/*
 * MCU type as defined in the ST header.
 */
#define STM32F042x6

/*
 * IO pins assignments.
 */
#define GPIOA_PIN0                  0U
#define GPIOA_PIN1                  1U
#define GPIOA_PIN2                  2U
#define GPIOA_PIN3                  3U
#define GPIOA_PIN4                  4U
#define GPIOA_PIN5                  5U
#define GPIOA_PIN6                  6U
#define GPIOA_PIN7                  7U
#define GPIOA_PIN8                  8U
#define GPIOA_PIN9                  9U
#define GPIOA_PIN10                 10U
#define GPIOA_PIN11                 11U
#define GPIOA_PIN12                 12U
#define GPIOA_SWDIO                 13U
#define GPIOA_SWCLK                 14U
#define GPIOA_PIN15                 15U

#define GPIOB_PIN0                  0U
#define GPIOB_PIN1                  1U
#define GPIOB_PIN2                  2U
#define GPIOB_PIN3                  3U
#define GPIOB_PIN4                  4U
#define GPIOB_PIN5                  5U
#define GPIOB_PIN6                  6U
#define GPIOB_PIN7                  7U
#define GPIOB_PIN8                  8U
#define GPIOB_PIN9                  9U
#define GPIOB_PIN10                 10U
#define GPIOB_PIN11                 11U
#define GPIOB_PIN12                 12U
#define GPIOB_PIN13                 13U
#define GPIOB_PIN14                 14U
#define GPIOB_PIN15                 15U

#define GPIOC_PIN0                  0U
#define GPIOC_PIN1                  1U
#define GPIOC_PIN2                  2U
#define GPIOC_PIN3                  3U
#define GPIOC_PIN4                  4U
#define GPIOC_PIN5                  5U
#define GPIOC_PIN6                  6U
#define GPIOC_PIN7                  7U
#define GPIOC_PIN8                  8U
#define GPIOC_PIN9                  9U
#define GPIOC_PIN10                 10U
#define GPIOC_PIN11                 11U
#define GPIOC_PIN12                 12U
#define GPIOC_PIN13                 13U
#define GPIOC_PIN14                 14U
#define GPIOC_PIN15                 15U

#define GPIOF_PIN0                0U
#define GPIOF_PIN1                1U
#define GPIOF_PIN2                  2U
#define GPIOF_PIN3                  3U
#define GPIOF_PIN4                  4U
#define GPIOF_PIN5                  5U
#define GPIOF_PIN6                  6U
#define GPIOF_PIN7                  7U
#define GPIOF_PIN8                  8U
#define GPIOF_PIN9                  9U
#define GPIOF_PIN10                 10U
#define GPIOF_PIN11                 11U
#define GPIOF_PIN12                 12U
#define GPIOF_PIN13                 13U
#define GPIOF_PIN14                 14U
#define GPIOF_PIN15                 15U

/*===========================================================================*/
/* Driver pre-compile time settings.                                         */
/*===========================================================================*/

/*===========================================================================*/
/* Derived constants and error checks.                                       */
/*===========================================================================*/

/*===========================================================================*/
/* Driver data structures and types.                                         */
/*===========================================================================*/

/*===========================================================================*/
/* Driver macros.                                                            */
/*===========================================================================*/
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

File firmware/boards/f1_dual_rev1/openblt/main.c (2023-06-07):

/****************************************************************************************
* Include files
****************************************************************************************/
#include "boot.h"                                /* bootloader generic header          */
#include "stm32f1xx.h"                           /* STM32 registers and drivers        */
#include "stm32f1xx_ll_rcc.h"                    /* STM32 LL RCC header                */
#include "stm32f1xx_ll_bus.h"                    /* STM32 LL BUS header                */
#include "stm32f1xx_ll_system.h"                 /* STM32 LL SYSTEM header             */
#include "stm32f1xx_ll_utils.h"                  /* STM32 LL UTILS header              */
#include "stm32f1xx_ll_usart.h"                  /* STM32 LL USART header              */
#include "stm32f1xx_ll_gpio.h"                   /* STM32 LL GPIO header               */

#include "io_pins.h"

/****************************************************************************************
* Function prototypes
****************************************************************************************/
static void Init(void);
static void SystemClock_Config(void);


/************************************************************************************//**
** \brief     This is the entry point for the bootloader application and is called
**            by the reset interrupt vector after the C-startup routines executed.
** \return    Program return code.
**
****************************************************************************************/
int main(void)
{
  /* initialize the microcontroller */
  Init();
  /* initialize the bootloader */
  BootInit();

  /* start the infinite program loop */
  while (1)
  {
    /* run the bootloader task */
    BootTask();
  }

  /* program should never get here */
  return 0;
} /*** end of main ***/


/************************************************************************************//**
** \brief     Initializes the microcontroller.
** \return    none.
**
****************************************************************************************/
static void Init(void)
{
  /* HAL library initialization */
  HAL_Init();
  /* configure system clock */
  SystemClock_Config();
} /*** end of Init ***/

/************************************************************************************//**
** \brief     System Clock Configuration. This code was created by CubeMX and configures
**            the system clock to match the configuration in the bootloader's
**            configuration (blt_conf.h), specifically the macros:
**            BOOT_CPU_SYSTEM_SPEED_KHZ and BOOT_CPU_XTAL_SPEED_KHZ.
**            Note that the Lower Layer drivers were selected in CubeMX for the RCC
**            subsystem.
** \return    none.
**
****************************************************************************************/
static void SystemClock_Config(void)
{
  /* Set flash latency. */
  LL_FLASH_SetLatency(LL_FLASH_LATENCY_2);
  if (LL_FLASH_GetLatency() != LL_FLASH_LATENCY_2)
  {
    /* Error setting flash latency. */
    ASSERT_RT(BLT_FALSE);
  }

  /* Enable the HSE clock. */
  LL_RCC_HSE_Enable();
  /* Wait till HSE is ready. */
  while (LL_RCC_HSE_IsReady() != 1)
  {
    ;
  }

  /* Configure and enable the PLL. */
  /* 48MHz max */
  LL_RCC_PLL_ConfigDomain_SYS(LL_RCC_PLLSOURCE_HSE_DIV_2, LL_RCC_PLL_MUL_12);
  LL_RCC_PLL_Enable();

  /* Wait till PLL is ready. */
  while (LL_RCC_PLL_IsReady() != 1)
  {
    ;
  }
  LL_RCC_SetAHBPrescaler(LL_RCC_SYSCLK_DIV_1);
  LL_RCC_SetAPB1Prescaler(LL_RCC_APB1_DIV_2);
  LL_RCC_SetAPB2Prescaler(LL_RCC_APB2_DIV_1);
  LL_RCC_SetSysClkSource(LL_RCC_SYS_CLKSOURCE_PLL);

  /* Wait till System clock is ready. */
  while (LL_RCC_GetSysClkSource() != LL_RCC_SYS_CLKSOURCE_STATUS_PLL)
  {
    ;
  }
  /* Update the system clock speed setting. */
  LL_SetSystemCoreClock(BOOT_CPU_SYSTEM_SPEED_KHZ * 1000u);
} /*** end of SystemClock_Config ***/


/************************************************************************************//**
** \brief     Initializes the Global MSP. This function is called from HAL_Init()
**            function to perform system level initialization (GPIOs, clock, DMA,
**            interrupt).
** \return    none.
**
****************************************************************************************/
void HAL_MspInit(void)
{
  LL_GPIO_InitTypeDef GPIO_InitStruct;

  /* AFIO and PWR clock enable. */
  LL_APB2_GRP1_EnableClock(LL_APB2_GRP1_PERIPH_AFIO);
  LL_APB1_GRP1_EnableClock(LL_APB1_GRP1_PERIPH_PWR);

  /* GPIO ports clock enable. */
  LL_APB2_GRP1_EnableClock(LL_APB2_GRP1_PERIPH_GPIOA);
  LL_APB2_GRP1_EnableClock(LL_APB2_GRP1_PERIPH_GPIOB);

#if (BOOT_COM_RS232_ENABLE > 0)
  /* UART clock enable. */
  LL_APB2_GRP1_EnableClock(LL_APB2_GRP1_PERIPH_USART1);
  /* UART TX and RX GPIO pin configuration. */
  GPIO_InitStruct.Pin = LL_UART_TX_PIN;
  GPIO_InitStruct.Mode = LL_GPIO_MODE_ALTERNATE;
  GPIO_InitStruct.Speed = LL_GPIO_SPEED_FREQ_HIGH;
  GPIO_InitStruct.OutputType = LL_GPIO_OUTPUT_PUSHPULL;
  LL_GPIO_Init(UART_GPIO_PORT, &GPIO_InitStruct);
  GPIO_InitStruct.Pin = LL_UART_RX_PIN;
  GPIO_InitStruct.Mode = LL_GPIO_MODE_FLOATING;
  GPIO_InitStruct.Pull = LL_GPIO_PULL_UP;
  LL_GPIO_Init(UART_GPIO_PORT, &GPIO_InitStruct);
#endif

#if (BOOT_COM_CAN_ENABLE > 0)
  /* CAN clock enable. */
  LL_APB1_GRP1_EnableClock(LL_APB1_GRP1_PERIPH_CAN1);
  /* CAN TX and RX GPIO pin configuration. */
  GPIO_InitStruct.Pin = LL_CAN_TX_PIN;
  GPIO_InitStruct.Mode = LL_GPIO_MODE_ALTERNATE;
  GPIO_InitStruct.Pull = GPIO_NOPULL;
  GPIO_InitStruct.Speed = LL_GPIO_SPEED_FREQ_HIGH;
  LL_GPIO_Init(CAN_GPIO_PORT, &GPIO_InitStruct);
  GPIO_InitStruct.Pin = LL_CAN_RX_PIN;
  GPIO_InitStruct.Mode = LL_GPIO_MODE_INPUT;
  GPIO_InitStruct.Pull = LL_GPIO_PULL_UP;
  LL_GPIO_Init(CAN_GPIO_PORT, &GPIO_InitStruct);
#endif

#if (BOOT_CPU_USER_PROGRAM_START_HOOK > 0)
  /* Configure GPIO pin for (optional) backdoor entry input. */
  GPIO_InitStruct.Pin = LL_GPIO_PIN_13;
  GPIO_InitStruct.Mode = LL_GPIO_MODE_FLOATING;
  LL_GPIO_Init(GPIOC, &GPIO_InitStruct);
#endif
} /*** end of HAL_MspInit ***/


/************************************************************************************//**
** \brief     DeInitializes the Global MSP. This function is called from HAL_DeInit()
**            function to perform system level de-initialization (GPIOs, clock, DMA,
**            interrupt).
** \return    none.
**
****************************************************************************************/
void HAL_MspDeInit(void)
{
  /* Reset the RCC clock configuration to the default reset state. */
  LL_RCC_DeInit();
  
  /* Deinit used GPIOs. */
  LL_GPIO_DeInit(GPIOB);
  LL_GPIO_DeInit(GPIOA);

#if (BOOT_COM_CAN_ENABLE > 0)
  /* CAN clock disable. */
  LL_APB1_GRP1_DisableClock(LL_APB1_GRP1_PERIPH_CAN1);
#endif
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

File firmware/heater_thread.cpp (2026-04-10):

#include "ch.h"
#include "hal.h"
#include "pwm.h"

#include "heater_control.h"
#include "port.h"
#include "sampling.h"

// 400khz / 1024 = 390hz PWM
static Pwm heaterPwm(HEATER_PWM_DEVICE);
static const PWMConfig heaterPwmConfig = {
    .frequency = 400'000,
    .period = 1024,
    .callback = nullptr,
    .channels = {{PWM_OUTPUT_ACTIVE_HIGH | PWM_COMPLEMENTARY_OUTPUT_ACTIVE_LOW, nullptr},
                 {PWM_OUTPUT_ACTIVE_HIGH | PWM_COMPLEMENTARY_OUTPUT_ACTIVE_LOW, nullptr},
                 {PWM_OUTPUT_ACTIVE_HIGH | PWM_COMPLEMENTARY_OUTPUT_ACTIVE_LOW, nullptr},
                 {PWM_OUTPUT_ACTIVE_HIGH | PWM_COMPLEMENTARY_OUTPUT_ACTIVE_LOW, nullptr}},
    .cr2 = 0,
#if STM32_PWM_USE_ADVANCED
    .bdtr = 0,
#endif
    .dier = 0};

class HeaterController : public HeaterControllerBase
{
public:
    HeaterController(int ch, int pwm_ch)
        : HeaterControllerBase(ch, HEATER_PREHEAT_TIME, HEATER_WARMUP_TIMEOUT)
        , pwm_ch(pwm_ch)
    {
    }

    void SetDuty(float duty) const override { heaterPwm.SetDuty(pwm_ch, duty); }

    // TODO: private:
public:
    const uint8_t pwm_ch;
};

HeaterController heaterControllers[AFR_CHANNELS] = {
    {0, HEATER_PWM_CHANNEL_0},

#if AFR_CHANNELS >= 2
    {1, HEATER_PWM_CHANNEL_1},
#endif

#if AFR_CHANNELS >= 3
    {2, HEATER_PWM_CHANNEL_2},
#endif

#if AFR_CHANNELS >= 4
    {3, HEATER_PWM_CHANNEL_3},
#endif
};

const IHeaterController& GetHeaterController(int ch)
{
    return heaterControllers[ch];
}

static THD_WORKING_AREA(waHeaterThread, 256);
static void HeaterThread(void*)
{
    chRegSetThreadName("Heater");

    // Wait for temperature sensing to stabilize so we don't
    // immediately think we overshot the target temperature
    chThdSleepMilliseconds(1000);

    // Configure heater controllers for sensor type
    for (int i = 0; i < AFR_CHANNELS; i++)
    {
        auto& h = heaterControllers[i];
        switch (GetSensorType())
        {
        case SensorType::LSU42: h.Configure(730, 80); break;
        case SensorType::LSUADV: h.Configure(785, 300); break;
        case SensorType::LSU49:
        default: h.Configure(780, 300); break;
        }
    }

    while (true)
    {
        auto heaterAllowState = GetHeaterAllowed();

        for (int i = 0; i < AFR_CHANNELS; i++)
        {
            const auto& sampler = GetSampler(i);
            auto& heater = heaterControllers[i];

            heater.Update(sampler, heaterAllowState);
        }

        // Loop at ~20hz
        chThdSleepMilliseconds(HEATER_CONTROL_PERIOD);
    }
}

void StartHeaterControl()
{
    heaterPwm.Start(heaterPwmConfig);

    for (int i = 0; i < AFR_CHANNELS; i++)
    {
        heaterPwm.SetDuty(heaterControllers[i].pwm_ch, 0);
    }

    chThdCreateStatic(waHeaterThread, sizeof(waHeaterThread), NORMALPRIO + 1, HeaterThread, nullptr);
}

float GetHeaterDuty(int ch)
{
    return heaterPwm.GetLastDuty(heaterControllers[ch].pwm_ch);
}

HeaterState GetHeaterState(int ch)
{
    return heaterControllers[ch].GetHeaterState();
}

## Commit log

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2020-09-20 cleanup & tweaks
    [wideband_controller.kicad_pcb, wideband_controller.sch]
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2020-09-20 add note
    [wideband_controller.sch]
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2020-09-21 layout help from dave
    [wideband_controller.kicad_pcb, wideband_controller.sch]
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2020-09-28 pcb tweakery
    [wideband_controller.kicad_pcb, wideband_controller.sch]
2020-10-10 fix jlc numbers
    [wideband_controller.kicad_pcb, wideband_controller.sch]
2020-10-14 switch to 14 pin stlinkv3 connector
    [wideband_controller.kicad_pcb, wideband_controller.sch]
2020-10-14 remove non-jlc from bom/pos
    [bom.csv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]
2020-10-14 update exports
    [pos.csv]
2020-10-26 fix pwm
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2020-11-28 add module
    [wideband_controller.kicad_pcb, wideband_controller.sch]
2020-11-28 add carrier
    [board_carrier.kicad_pcb, board_carrier.sch]
2020-11-28 debug header
    [wideband_controller.kicad_pcb, wideband_controller.sch]
2020-11-29 carrier with mx120
    [board_carrier.kicad_pcb, board_carrier.sch]
2020-11-29 add jumper for addr sel
    [wideband_controller.kicad_pcb, wideband_controller.sch]
2020-11-29 carrier export settings
    [board_carrier.kicad_pcb]
2020-11-29 switch to F103
    [wideband_controller.kicad_pcb, wideband_controller.sch]
2020-12-01 switch to lqfp32
    [wideband_controller.kicad_pcb, wideband_controller.sch]
2020-12-01 carrier mods
    [board_carrier.kicad_pcb, board_carrier.sch]
2020-12-01 carrier probably done
    [board_carrier.kicad_pcb, carrier_bom.csv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]
2020-12-01 add logo to back
    [wideband_controller.kicad_pcb]
2020-12-01 module export
    [module_bom.csv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]
2020-12-01 schematic export
    [wideband_controller.sch]
2020-12-01 add tiny firmware flash tool
    [board_fw_tool.kicad_pcb, board_fw_tool.sch]
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2020-12-01 add CAN caps, solid reg pad
    [board_carrier.kicad_pcb, board_carrier.sch, board_fw_tool.kicad_pcb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]
2020-12-01 add a few caps
    [wideband_controller.kicad_pcb, wideband_controller.sch]
2020-12-01 add an led
    [wideband_controller.kicad_pcb, wideband_controller.sch]
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2020-12-11 Revert "switch to nil"
    This reverts commit d3a9f34eafebe3933ca25f97ce515375215e405e.
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2020-12-11 fix board pinout
2020-12-11 detect sensor overheat
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2020-12-11 fix uart pinout
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2020-12-22 add nrst cap #3
    [wideband_controller.kicad_pcb, wideband_controller.sch]
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2020-12-30 add voltage ref
    [wideband_controller.kicad_pcb, wideband_controller.sch]
2020-12-30 moar caps
    [board_carrier.kicad_pcb, board_carrier.sch]
2020-12-30 switch to better diode
    [board_carrier.sch]
2020-12-30 lower voltage tvs
    [board_carrier.sch]
2020-12-30 more stitching
    [board_carrier.kicad_pcb]
2020-12-30 version text
    [board_carrier.kicad_pcb]
2021-01-01 tweak pour
    [board_carrier.kicad_pcb]
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2021-01-17 correct for resistor
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2021-03-18 pwm doesn't work without this
    [pwm.cpp]
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2021-04-27 disable pump in case of problems
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2021-05-19 Add case design files
    [board_carrier.step.SLDASM, case.STL]
2021-05-19 hardware ID set
    [wideband_controller.kicad_pcb, wideband_controller.sch]
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2021-11-08 Extract io (#25)
    * LEDs for BL
    * more reuse
    * Windows exists
    * extract NERNST pin
    * Matt is asking to move
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2022-01-02 Correct dac timer (#38)
    * DAC uses proper timer now
    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
    [io_pins.h]
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2022-04-06 f1_dave: board cleanup and pinmux fixes (#56)
    * f1_dave: clean-up board.h
    * f1_dave: PB6 should be output+alternate
    Set using VAL_GPIOBCRL, no need to call palSetPadMode
    * f1_dave: PB12 ESR driver, should be high speed (hi current)
    * f1_dave: PB13 - Blue LED should be output push-pull
    * f1_dave: fix pinmuxes, add comments
    [board.c, board.h]
2022-05-07 Temperature (#63)
    * integer id interpolation
    * Calculate sensor temperature based on Ri
    * Sensor Ri around 25C
2022-05-11 Uart debug (#64)
    * heater: export state and description
    * pump_dac: save and export Ipump
    * float interpolation helpers
    * Show heater state, heater duty, temperature and fault over uart
    * uart: more stack for thread
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2022-06-22 f1_dave: PA1 is pump PWM output, should be alternate (#75)
    (cherry picked from commit b31e642943bdb49470ef091d1657ce1bf62301f8)
2022-06-24 Prepare for multi-channel boards (#72)
    * Prepare for multi-channel boards
    (cherry picked from commit 8b713cebfca9772fa1742ef5a21cae1b9337951b)
    * this belongs in wideband_board_config.h they say
2022-06-29 Steal tunerstudio files from RusEFI (#71)
    * Steal tunerstudio files from RusEFI
    (cherry picked from commit dcba04fbd31700f5ca4ef4f12a6e220c5713c7d0)
    * Steal crc32 files from RusEFI
    (cherry picked from commit bfe88b5297c6fc90c8e647e4144c91edafef25f9)
    * fix TS steal
    (cherry picked from commit a77b9761da4c185359bb2d7e10abd6a8e69c740d)
    * fix crc32
    (cherry picked from commit cdb4df09f69c2494316c2b12f97dbe19f6bdb598)
    * TS stealed from RE
    (cherry picked from commit ff470e134036372425da44e9e0fb98737f31c9e9)
    * Steal TS
    (cherry picked from commit d11406edc2d6b3c1567ce800e207038745a162e7)
    * Steal Thread Controller
    (cherry picked from commit 2aa5bbd57150e0d5b51e2e8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
2022-06-29 0624 pwm (#81)
    * pwm.cpp: support multichannel
    (cherry picked from commit 27995893ee181e699b8e0ab33283dfcc581fcc88)
    * pwm.cpp: allow external config
    (cherry picked from commit 70856151b7fee72f2a9c1a6013801ab14c2bffdb)
2022-06-29 GD32: ADC workaround (#83)
    (cherry picked from commit 02fd9f248189e3e801b50c920e1166daa23283bc)
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2022-07-01 f1_rev2: set O0 optimization level due to issue with ADC on GD32 (#94)
2022-07-01 0701 rev2 2 (#91)
    * Rev 2: VM_RESISTOR_VALUE
    (cherry picked from commit 84ae91fc67cf6764afd5b00210edbc3cfe4444a5)
    * Rev 2: default settings for LSU4.9
    (cherry picked from commit 5a1fe84bc1ec8d7ee6e0a5f2906a1b18d2ff8a8e)
    * Per-board VM_RESISTOR_VALUE
    (cherry picked from commit 0bdd19e058db579bed13488066df1176ea9addb2)
    * Rev2: ID correct pins
    (cherry picked from commit 59e4b36ad9bc7c166c3dae7e25b6317caf562056)
    * Rev2: LSU 4.2 and ADV ESR drive pins
    (cherry picked from commit 2f2b4399431136951fe2fa6819f44ba28c3cda17)
    * Rev2: aux pwm pins: no need to be 50MHz fast
    (cherry picked from commit b0af5c07c391438ca561118174df498207255f3b)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
    [board.h, io_pins.h, wideband_board_config.h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]
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2022-07-02 Rev2: GD32 ADC workaround (#96)
2022-07-03 Board Rev 2 (#98)
    * f1_rev2: fix for new AnalogResult format
    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
2022-07-04 f1_rev2: OpenBLT: update gpio and interfaces setup (#97)
    * f1_rev2: OpenBLT: update gpio and interfaces setup
    * f1_rev2: OpenBLT: set default board name
    * f1_rev2: no need to have bootloader region in main app LD file
    * f1_rev2: use gpio settings from application include file
    * f1_rev2: OpenBLT: update gpio and interfaces setup
    * f1_rev2: OpenBLT: close backdoor
    * f1_rev2: OpenBLT: fix uart setup
    * f1_rev2: OpenBLT: gracefully close CAN after use
    [io_pins.h, main.c]
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2022-07-14 Introducing dual channel board (#109)
    * port: ID_SEL2_PIN is optional
    Dual version is out of mcu pins and implement only one sel pin.
    * board: f1_dial: add dual channel board
    * GH actions: add f1_dual build to actions
    * f1_dual: use uart driver, not serial
    * f1_dual: setup correct remaps
    * f1_dual: DEBUG: enable uart debug (disable TS)
    * board: f1_dual: add way to measure battery through Heater-
    * fix dual board
    [board.c, board.h, io_pins.h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]
2022-07-15 f1_dual: set O0 optimization level due to ADC issue on GD32 (#116)
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2022-07-15 Ts top down (#104)
    * TS top down
    * TS top down
    * TS top down
    * TS top down
    * Ts top down #104
    removing the controversial part
    * Ts top down #104
    removing the controversial part
    * fix build (switch to serial)
    * f1_dual: UART->Serial
    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
    [uart.cpp, wideband_board_config.h]
2022-07-16 f1_dual: fix aux pwm outputs (#119)
    [auxout.cpp]
2022-07-20 Add max31855 driver (#103)
    * Add max31855 driver
    * f1_dual: enable EGT driver
    * bit.h: bit helper
    * max31855 driver progress
    * max31855 driver fixing guard
    [io_pins.h, main.cpp, uart.cpp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]
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2022-08-30 Multichannel (#134)
    * Multichannel AFR
    * heater: fixes for multi channel mode
    * f1_dual: fix configuration names
    * pump_dac: fixes for multi-channel mode
    * pwm: fixes for multichannel mode
    * pump_control: reference instead of pointer
    * sampling: reference instead of pointer
    * heater_control: reference instead of pointer
    * sampling: comment about heater/battery voltage
    * f0_module: fixes for multi-channel update
    * f1_rev2: fix for multichannel AFR
    * hello rev 3
    [auxout.cpp, heater_control.h, io_pins.h]
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2022-09-20 Livedata update (#163)
    * max31855: add EGT to livedata
    * livedata: getEgtLiveDataStructAddr() returns NULL for boards with no EGT
    * livedata: report AFR sensor(s) state
    * livedata: report heater state
    * uart: fix for max31855 update
    [uart.cpp]
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2022-12-07 avoid bogus temperature with disconnected sensor
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2023-01-06 consolidate in hardware folder
    [board_carrier.kicad_pcb, board_carrier.sch, board_fw_tool.kicad_pcb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]
2023-01-16 Fix fault handlers for Cortex-M0 (#180)
    [main.cpp]
2023-01-23 f1_dual/rev3: Revert CPU clock back to 48 MHz due to ADC problems on GD32 (#181)
2023-01-29 TS minor fixes (#178)
    * ts: fix copy-paste
    * TS: fallback to default baudrate if BT setup failed
    * io_serial: BT setup: no goto
    * ini: dual: fix typo
    * ts: BT: fix baudrate switch when using JDY33
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2023-02-03 module revision update to kicad 6 break out SEL pins add 4.2/ADV support switch to TC2030 programming header
    [wideband_controller.kicad_pcb, wideband_controller.kicad_sch, wideband_controller.sch]
2023-02-03 kicad 6
    [board_carrier.kicad_sch, board_carrier.sch]
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2023-02-03 reroute carrier for proper footprint
    [board_carrier.kicad_pcb, board_carrier.kicad_sch]
2023-02-03 vbatt sense
    [board_carrier.kicad_pcb, board_carrier.kicad_sch, wideband_controller.kicad_pcb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]
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2023-02-13 move old hardware to archive folder
    [board_fw_tool.kicad_pcb, board_fw_tool.sch, bom.csv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]
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2023-02-15 Warning (#200)
    * AUX out: cleanup warning
    (cherry picked from commit f52b12c5d77ed537060eca4ba4a48392ed8e2418)
    * HardFault handler: fix unused warning
    (cherry picked from commit 6baa0fc1207142990b1501354a2b88ea322f1c4f)
    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
    [auxout.cpp, main.cpp]
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2023-02-20 move rev A
    [module_bom.csv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]
2023-02-20 rev b export
    [BOM-wideband_controller.csv, wideband_controller.kicad_pcb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]
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2023-04-27 Dual 1 (#241)
    * f1_dual_rev1: add pinmux settings for port F and G
    To supress compiler warning.
    (cherry picked from commit 89876fe8eaad933308b63a4b0b1666deb75bfc84)
    * f1_dual_rev1: fix remaps
    -disable JTAG to free PA15, PB3, PB4
    -use SPI3 for EGT chips without remaping
    (cherry picked from commit 598f1aa0779ba6e90ccf2eb74445d074f2bfbc75)
    * f1_dual_rev1: disable unused TIM1, TIM2
    (cherry picked from commit 9e71c3813fd09c080c0eb2f1e63fe82b475efb4f)
    * f1_dual_rev1: run at 72MHz from HSE
    (cherry picked from commit eaa4577ef85bdfdba637c203646883202a1f8e02)
    * f1_dual_rev1: fix can timings
    (cherry picked from commit 6437b3d92047adefe6534efaa57062bdda449d37)
    * f1_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
    [board.c, board.h, wideband_board_config.h]
2023-04-29 Aux2 (#243)
    * auxout: manually fill pwm config
    (cherry picked from commit a01876bc034264de5d6930bf2cc49cf0fc0cbb0a)
    * auxout: some boards use primary PWM outputs instead of complementary
    (cherry picked from commit c13b95441e7b284a36445c261199e96580e94ebd)
    * auxout: implement ripple cancelation using inverted PWM
    (cherry picked from commit 77cbc04990421b24021639b098ea6040af3a12f8)
    * f1_common: default AUXOUT value is AFR voltage
    with 'default' scaling 8.5 to 18.0 AFR is represented with 0.0 to
    5.0V
    (cherry picked from commit 0c62ab8f509ff0ab3ab4260e308ad4b55bd64e40)
    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
    [auxout.cpp, io_pins.h]
2023-04-29 f1_dual_rev1: update ADC, measure Un_sense, avoid clamping (#244)
    (cherry picked from commit 26f12766968a1999e1f12e06720ecbc334a91add)
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2023-05-03 Rev 1pwm (#242)
    * f1_dual_rev1: fix analog aux output PWM definitions
    (cherry picked from commit 50e346dfcb9f223c6e0ee6cdc700cb376b536834)
    * fix pwm definitions
    (cherry picked from commit ce9e69b997290bbd7abcfe5af2926b1d556070cf)
    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
    [io_pins.h]
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2023-05-29 auxout: no need to invert PWM signal in software (#248)
    [auxout.cpp, io_pins.h]
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2023-05-29 f1_dual_rev1: fix SPI1 remap (#252)
    (cherry picked from commit 38037e8b46ea4f9c2dd370560e6138ed35ade2f7)
    [board.c]
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2023-05-29 f1_common: fix MFS flash allocation for STM32F103RCT6 used on dual_rev1 (#260)
    (cherry picked from commit 258d33e8a7b79846afd4e0db791d87476b9d2041)
    [board.h]
2023-06-07 max3185x: fix compilation warning (#264)
    (cherry picked from commit 083defaaf2dd20498939ca5ddd40195a2484c33b)
    [max3185x.cpp]
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2023-06-11 OpenBLT reset functionality (#259)
    * ts: support reset and reset to OpenBLT commands
    (cherry picked from commit 2f2fca401d7dc9a29e806013efec4d41570dd613)
    * f1_xxx: ini: reset commands
    (cherry picked from commit 628994ba0a70901edb9b59360646aa195b3307cf)
    * typo
    * f1_xxx: ini: update signature
    (cherry picked from commit 7aa57fe09c6c684855838e36c9b65d8ae3618a7a)
    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
    [wideband_board_config.h]
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2023-08-09 bugfix: adding brackets for proper Operator Precedence (#275)
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2023-11-15 Mess (#282)
    * f1_dual_rev1: fix Heater vs Battery naming mess
    * f1_dual: fix Heater vs Battery naming mess
    * fix f1_dual_rev1
    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
    [wideband_board_config.h]
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2023-11-18 F0 heater was broken by cddcd0d88c6fd2d09c61412ca01b8a1bc0c373b8
    [heater_thread.cpp]
2023-11-18 avoid NaN in case of zero battery voltage
2023-11-19 heater: shortcut if sensor is hot enough (#277)
    * heater: shortcut if sensor is hot enough
    * heater: shortcut if sensor is hot enougth
    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
    [wideband_board_config.h]
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2023-11-23 F0 doesn't need UART
2023-12-03 TS_ENABLED vs ENABLE_TS: fix mess (#301)
    board.mk defines ENABLE_TS for Makefile
    while Makefile defines TS_ENABLED for compiled code.
    Use TS_ENABLED in main.cpp
    [main.cpp]
2024-06-26 Underheat issue (#314)
    * f0_module needs hack to start pump before closed loop
    * Fix paranoid check
    * Make START_PUMP_TEMP_THRESHOLD relative
    [heater_control.h, pump_dac.cpp, wideband_board_config.h]
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2024-06-26 suggestion to improve naming (#294)
    * Rename GetInternalBatteryVoltage() to GetInternalHeaterVoltage()
    * sampling, heater: fix Battery vs Heater naming mess
    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
    [uart.cpp]
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2024-09-25 fix heater control timer test
2025-01-23 fix uart debug
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2025-01-24 heater thread iterate correctly
    [heater_thread.cpp]
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2025-01-27 Fix f1 compilation (#324)
    * f1_common: new MFS API
    * max3185x: new SPI API
    [max3185x.cpp]
2025-01-28 correct heater thread channel numbers
    [heater_thread.cpp]
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2025-01-31 Max3185x update (#328)
    * max3185x: more const
    * max3185x: deinit SPI bus after use
    * max3185x: improve chip type detection
    * max3185x: no magic numbers
    * max3185x: check spi_txrx return value
    * max3185x: simplify, fix negative values for max31856
    * max3185x: SPI ts buffer is const
    * max3185x: paranoid check for max31856
    * max3185x: start in proper state
    * max3185x: communication error counter to TS
    [max3185x.cpp]
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2025-08-22 remove NoHeaterSupply state (#292)
    * remove NoHeaterSupply
    * remove matching status
    * avoid low supply voltage -> infinite duty
    [heater_control.h]
2025-10-13 read the correct byte for pump gain
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2026-03-22 update kicad & bom tweaks
    [wideband_controller.kicad_pcb, wideband_controller.kicad_sch]
2026-03-22 rev C: just BOM improvements
    [BOM-wideband_controller.csv, wideband_controller.kicad_pcb, wideband_controller.kicad_sch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]
2026-03-22 update LED PNs
    [BOM-wideband_controller.csv, wideband_controller.kicad_pcb, wideband_controller.kicad_sch]
2026-04-10 fix typo BATTETY -> BATTERY
    [wideband_config.h]
2026-04-10 avoid trying to heat when battery voltage is low
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2026-10-24 Add an analog output (#352)
    * working pwm out
    * add a hacky knob for pump gain over CAN
    * working pwm out
    * plumb other sensors
    * io pins define
    * restore default pump PID
    * Fix sensor select
    * drop some leftovers
    * missing tab
    * streamline this
    * fix memory overflow
    * pollution
    * remove pollution
    * newlines
    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
2026-11-07 correct analog out pwm device
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2026-11-09 test PID, avoid a divide, avoid derivative calc if kD == 0 #353
